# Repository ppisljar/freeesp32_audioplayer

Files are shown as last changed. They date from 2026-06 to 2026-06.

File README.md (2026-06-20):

# freeesp32_audioplayer

Open-source ESP32 audio playback board designed primarily as the hardware
platform for [**`freeesp32_ave`**](https://github.com/ppisljar/freeesp32_ave) —
audio-visual entrainment (AVE) firmware.

This repository contains the full **KiCad** project: schematic, PCB layout,
design rules, 3D models, datasheets, and helper scripts.

## Board renders

| Top | Bottom |
|---|---|
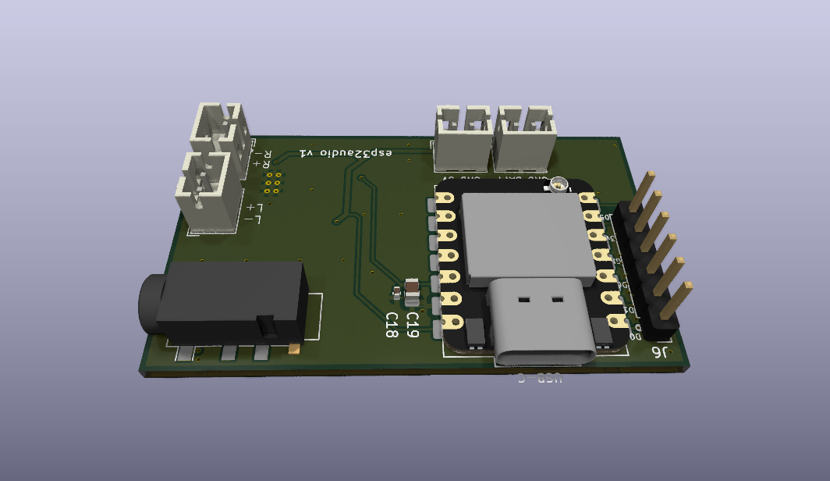
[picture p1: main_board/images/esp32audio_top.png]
Top view
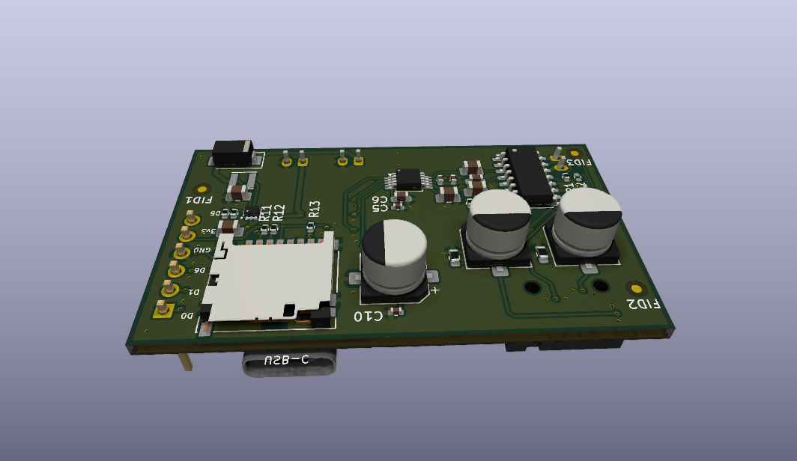
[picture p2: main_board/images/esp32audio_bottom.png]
Bottom view
|  |  |

*KiCad 3D renders. Top: TRRS headphone jack, USB-C, microSD slot, XIAO ESP32-S3 module, LED/expansion pin headers. Bottom: speaker amplifier (APA2068), bulk capacitors, level-shifting resistors.*

## Board features

- **MCU module**: Seeed Studio **XIAO ESP32-S3** (Wi-Fi + BLE)
- **Headphone output**: Cirrus Logic **CS4344** stereo I²S DAC
- **Speaker output**: **APA2068** Class-D power amplifier
- **Storage**: microSD card slot for offline audio and timeline files
- **LED outputs**: configurable headers — works with NeoPixel (WS2812),
  DotStar (APA102), or direct PWM strips (the firmware picks the backend)

## Power

The board can be powered any of three ways. The 5 V rail feeds the speaker
amplifier (APA2068), and the XIAO's onboard LDO derives the 3.3 V rail
that feeds the DAC (CS4344) and the MCU itself.

| Source | Connector | Voltage | Notes |
|---|---|---|---|
| **USB-C** | XIAO ESP32-S3 onboard | 5 V (USB VBUS) | Also used for flashing firmware and the serial console. The default during development. |
| **External 5 V** | `J4` — JST PH 2-pin (`V+_EXT`) | 5 V regulated | For powering from a bench supply, wall adapter, or upstream USB-PD trigger. |
| **Li-ion battery** | `J5` — JST PH 2-pin (`BATTERY`) | 3.0 – 4.2 V | Connects to the XIAO's `BAT+` pin. The XIAO's built-in charger manages the cell when USB is also plugged in. |

### Battery-powered audio

A single Li-ion cell sits below the 5 V needed by the speaker amplifier,
so the board includes a **TPS61023 synchronous boost converter** (`U4`)
that lifts `BAT+` up to 5 V. Output is fed into the 5 V rail through a
Schottky diode (`D1`) so the boost output can't backfeed USB VBUS when
both USB and battery are connected.

This means the speaker output works on battery just as well as on USB —
no compromise.

### Combining sources — what's safe

| Combination | Safe? | Why |
|---|---|---|
| USB + battery | ✅ Yes | XIAO charges the cell; `D1` blocks the boost from feeding USB. |
| USB + external 5 V (`J4`) | ❌ **No — pick one** | Both feed the 5 V rail directly. Hot-swapping risks back-feeding the upstream supply. |
| External 5 V + battery | ✅ Yes | Same reasoning as USB + battery — `D1` isolates the boost. |

> **Tip**: if you intend to deploy the board untethered in a meditation
> session, leave USB unplugged once you've flashed the firmware. The
> XIAO's USB controller draws current even when the host is idle.

## Repository layout

```
main_board/
├── esp32audio.kicad_sch    # schematic
├── esp32audio.kicad_pcb    # PCB layout
├── esp32audio.kicad_pro    # KiCad project
├── 3dmodels/               # STEP models for enclosure design
├── datasheets/             # IC datasheets and reference schematics
├── analysis/               # generated reports (regenerable from source)
├── images/                 # 3D renders used in this README
├── outputs/                # gerbers, drill files, BOM, pick-and-place CSVs
└── *.py                    # helper scripts (netlist sync, freerouting…)
```

## Related projects

| Repo | Role |
|---|---|
| [`freeesp32_audioplayer`](https://github.com/ppisljar/freeesp32_audioplayer) | **This repo** — open hardware (KiCad) |
| [`freeesp32_ave`](https://github.com/ppisljar/freeesp32_ave) | AVE firmware that runs on this board |
| [`freeesp32_ave_generator`](https://github.com/ppisljar/freeesp32_ave_generator) | Web editor that generates session timelines for the firmware |

## Ordering the board

The `main_board/outputs/` directory contains everything a PCB fab needs:

| File / folder | Purpose |
|---|---|
| `outputs/Archive.zip` | Gerbers + drill file (KiCad standard layer naming) |
| `outputs/esp32audio.csv` | BOM with manufacturer part numbers (MPNs) |
| `outputs/esp32audio-*-pos.csv` | Pick-and-place coordinates (top / bottom / all) |

### PCBWay (recommended for assembly with non-LCSC parts)

1. Go to <https://www.pcbway.com/orderonline.aspx> and upload `outputs/Archive.zip`. The site auto-detects board size, layer count (2-layer), and finish.
2. Defaults are fine: **FR-4, 1.6 mm, HASL or ENIG, green soldermask, white silkscreen**.
3. For assembly: enable **PCB Assembly**, upload `esp32audio.csv` (BOM) and `esp32audio-top-pos.csv` + `esp32audio-bottom-pos.csv` (CPL). PCBWay sources parts by MPN globally — useful if any component is out of stock on LCSC.
4. Quoting + DFM review typically completes within 24 h; bare-board lead time ~3–5 days, assembled ~7–10 days.

### JLCPCB (cheaper for bare boards / parts available on LCSC)

1. Go to <https://cart.jlcpcb.com/quote> and upload `outputs/Archive.zip`.
2. Defaults are fine. JLCPCB's free options match what this design needs.
3. For assembly: enable **PCBA**, upload `esp32audio.csv` (BOM) and `esp32audio-all-pos.csv` (CPL). JLCPCB requires the parts to be in their LCSC catalog — verify MPN availability before ordering, and substitute equivalents in the BOM where needed.

### Bare-board only (any fab)

Just upload `outputs/Archive.zip` — the gerbers use KiCad's standard layer naming (`F_Cu`, `B_Cu`, `F_Mask`, `B_Mask`, `F_Paste`, `B_Paste`, `F_Silkscreen`, `B_Silkscreen`, `Edge_Cuts`) which every modern fab recognises.

### Regenerating outputs from source

If you edit the schematic or PCB, regenerate the manufacturing files from KiCad:

- **PCB → File → Fabrication Outputs → Gerbers…** (use `outputs/` as the output directory, then zip)
- **PCB → File → Fabrication Outputs → Drill Files…**
- **PCB → File → Fabrication Outputs → Component Placement…** (top + bottom CPL)
- **Schematic → Tools → Generate BOM…**

## Status

Hardware design in active development. See `main_board/project_plan.md` and
`main_board/lessons_learned.md` for design notes.

## License

TBD — open hardware license to be chosen (e.g. CERN-OHL-S 2.0).

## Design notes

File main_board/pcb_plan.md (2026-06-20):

# esp32audio — PCB layout plan

Mixed-signal board with a switching boost converter and a Class-D amp.
The biggest layout risks are switching-noise coupling into the analog
audio path and inadequate return current management. Plan below is
optimised for that.

---

## 1. Board outline and stackup

| Topic | Decision |
|---|---|
| Outline target | **~42 x 32 mm** (≈ 1350 mm²), rounded 1 mm corners. Stretch goal 40 x 30. Hard ceiling 45 x 35. |
| Layer count | **2-layer**, **components on BOTH sides** to hit the size target |
| Copper weight | 1 oz (35 µm) standard |
| Substrate | FR-4, 1.6 mm |
| Top side (component-heavy) | XIAO, all 4 ICs, all connectors, the three electrolytic caps (C11, C13, C14), L1, D1 |
| Bottom side (small SMD only) | All 0603 decoupling caps, all 0603/0805 ceramics that fit, all 0603 resistors, FB divider, VOLUME divider, SE/BTL divider, FB-loop resistors |
| Stackup notes | Still 2-layer, but bottom is no longer a pure ground pour — it carries small SMDs in patches between the ground pour. Discipline: every bottom-side passive sits on a copper island connected to its corresponding top-side pin by a single via per pad. The pour fills around them. |
| Fab assumption | JLCPCB design rules (6/6 mil trace/space, 8 mil min annular, 0.3 mm min hole) |
| Assembly assumption | JLCPCB SMT both sides (extra cost vs. one side, but worth it for the area savings). Hand-solder fallback OK — all bottom parts are passives. |

Size-vs-quality reasoning: a 2-layer board with components on both
sides preserves the single-ground-pour discipline (§4) as long as
bottom-side passive islands are small and the pour stitches around
them. The audio path stays on the top layer end-to-end. The boost
island stays on the top layer end-to-end. We only lose pour
continuity in patches under decoupling caps — those patches are
< 5 mm wide and shielded by the IC body above, so they do not
disrupt audio return paths.

Switching node area, audio bandwidth, and ground-pour discipline
arguments still apply unchanged from the single-side plan.

---

## 2. Floor plan — XIAO on south edge, USB-C facing south

```
       ┌──────────────────────────────────────────────────┐
       │ [J5 BAT screw]    [J4 V+ JST]      [J1 3.5mm jack]│  NORTH edge
       │                                                  │
       │ [boost island:                     [J2 L spkr]    │  (connectors NORTH)
       │   U4,L1,C16,                                      │
       │   C17,D1]          [APA2068 U3]    [J3 R spkr]    │
       │                                                  │
       │ [J6 GPIO     [CS4344 U2]                          │
       │   breakout                                        │
       │   1x10       (audio chain in middle row)          │
       │   pin hdr]                                        │
       │                                                  │
       │      [────  XIAO ESP32-S3 (U1) ────]              │  SOUTH edge
       └────────────────↓ USB-C overhang ↓────────────────┘
                       (clear board edge south)
```

The XIAO is the size-driver. Pinning its USB-C to one edge defines
that edge; everything else fits around it.

**XIAO orientation (locked):**

- XIAO long axis runs **east-west** along the south edge of the
  board.
- USB-C connector points **south**, overhanging the board edge by
  ~1.5 mm so the USB-C plug shell clears any silkscreen / soldermask
  pile-up.
- Castellated mount: BAT+ SMD pad (bottom of XIAO module) sits on a
  matching copper land on the top layer of the board. Verify the
  XIAO_ESP32-S3_SMD footprint exposes this pad; if it does not, fix
  the .kicad_mod before placement.
- Board edge directly under the USB-C must be straight (no rounded
  corner) for ~6 mm centered on the connector — round corners
  reduce strain relief but a USB-C plug needs a flat seat.
- No tall components within 3 mm north of the XIAO body — the
  module's antenna sits on its top face and benefits from clear
  space.

Edge ownership (so cables don't fight):

| Edge | Connectors |
|---|---|
| North | J5 battery screw (left), J4 V+ JST (center), J1 headphone (right) |
| East | J2 L speaker, J3 R speaker (stacked vertically) |
| West | J6 GPIO breakout (1x10 SIL header, vertical) |
| South | XIAO U1, USB-C overhang only — no other connector |

Trade-off: J5 (battery screw) and J1 (headphone) on the same edge
means the user must route the battery wire away from the headphone
plug when the device is held normally. Acceptable — the alternative
(headphone on east, speakers on north) makes the east edge cluttered
with one BIG part and three small ones.

---

## 2a. Top vs bottom side assignment

Every part is placed on exactly one of the two sides. The board is
designed so that **everything on the bottom is a small passive** —
no ICs, no electrolytics, no connectors, no tall parts on the
bottom. This keeps assembly cheap and lets the board sit flat on a
case.

### TOP side (north view)

All ICs, the XIAO module, all connectors, all electrolytic /
through-hole / tall parts, the boost inductor and Schottky.

| Ref | Part | Reason for top |
|---|---|---|
| U1 | XIAO ESP32-S3 module | Castellated SMD; antenna up |
| U2 | CS4344 TSSOP-10 | Main IC |
| U3 | APA2068 SOP-16-EP | Main IC, EP needs top-side via field |
| U4 | TPS61023 SOT-563 | Main IC |
| L1 | 4.7 µH SMD inductor | Tall, magnetic — keep above plane |
| D1 | SS14 Schottky | Part of boost loop, keep with L1 |
| C11 | 100 µF electrolytic | Tall radial / SMD lead |
| C13 | 220 µF electrolytic (HP L) | Tall |
| C14 | 220 µF electrolytic (HP R) | Tall |
| J1–J6 | All connectors | Through-hole or large SMD |

### BOTTOM side (small SMD passives only, 0603/0805)

| Ref | Part | Goes near |
|---|---|---|
| C2 | 0.1 µF | Under CS4344, snug to pin 9 (VA) |
| C3 | 1 µF | Under CS4344, near pin 9 |
| C4 | 10 µF | Under CS4344, snug to pin 6 (FILT+) |
| C5 | 0.1 µF | Under CS4344, snug to pin 5 (VQ) |
| C6 | 3.3 µF | Under CS4344, near pin 5 |
| C7 | 3.3 µF poly | Mid-path CS4344↔APA2068 (could be on top if 0805 polarised cap is fine on top) |
| C8 | 3.3 µF poly | Mid-path CS4344↔APA2068 |
| C9 | 0.1 µF | Under APA2068, snug to pin 10 (VDD) |
| C10 | 0.1 µF | Under APA2068, snug to pin 15 (VDD) |
| C12 | 2.2 µF | Under APA2068, snug to pin 4 (BYPASS) |
| C15 | 0.1 µF | Under APA2068, snug to pin 7 (VOLUME) |
| C16 | 10 µF | Under U4, snug to pin 3 (VIN). Keep on TOP if it fits the boost-island rule (see §3.1) |
| C17 | 22 µF | Under U4, snug to pin 6 (VOUT). Same caveat |
| R1, R2 | 100k | Under APA2068, near pin 13 (SE/BTL) |
| R3, R4 | 1k | Under HP path, near J1 |
| R7, R8 | VOLUME divider | Under APA2068, near pin 7 |
| R9, R10 | FB divider | Under U4, near pin 1 (FB) |

**Caveat for C16, C17:** the boost-island rule (§3.1) requires the
input/output caps to close their current loop with U4 via the
shortest possible path. If putting C16/C17 on the bottom forces the
loop to detour through vias (adding inductance), keep them on the
top side flanking U4 instead. Decide during placement based on what
visually closes the loop tightest. The rest of the bottom-side
assignments are unconditional.

### Bottom-side ground-pour rule

The bottom layer is **mostly ground pour**, with small copper
patches for the bottom-side passive pads. Each bottom-side pad
connects to its top-side function via a single via per pad, placed
on the pad itself (via-in-pad, or tab-and-via if fab forbids
via-in-pad). The pour stitches around these patches.

Result: viewed from below, the board looks like solid copper with a
few tiny copper-and-pad islands. The audio return path under
top-side traces is preserved everywhere except those islands.

---

## 2b. Size optimization checklist

Run through this list during placement. Each item is worth 1–5 mm²
of saved area.

- [ ] **XIAO USB-C overhangs the south edge** (saves ~3 mm of board
      length compared to fully containing the connector)
- [ ] **All small passives on the bottom side** (saves the area they
      would otherwise occupy on top)
- [ ] **Decoupling caps directly under their IC pin** (zero
      additional top-side area)
- [ ] **No silkscreen reference designators on tight bottom-side
      patches** — they push pours apart; use a separate top-side ref
      legend or rely on the BOM for ref positions
- [ ] **JST PH-2 connectors share centerlines** where multiple sit
      on the same edge (J4 with J2/J3 styled the same, mounted
      flush)
- [ ] **J6 GPIO header oriented vertically along west edge** (uses
      the full west edge in one strip instead of a horizontal block
      that eats interior area)
- [ ] **APA2068 EP vias fit inside the package footprint** (no extra
      copper required beyond the EP outline)
- [ ] **Boost island fits in a 12 x 12 mm square**; if it spreads
      beyond that, re-pack
- [ ] **No "test point" pads on v1** — leave testpoints for v1.1 if
      we discover we need them. Each TP eats 2.5 mm²
- [ ] **Mounting holes deferred to v1.1** OR use M2 holes (≤ 4.5 mm
      keep-out each), placed only at two diagonal corners
- [ ] **Silkscreen kept to essentials**: pin 1 dots, polarities,
      J5/J6 labels, board name. No full pinouts on every connector.

### Realistic size budget

| Element | Area used |
|---|---|
| XIAO under-area (21 x 17.5) | 367 mm² |
| APA2068 + decoupling | ~50 mm² |
| CS4344 + decoupling | ~30 mm² |
| Boost island | ~120 mm² |
| C11, C13, C14 electrolytics | ~90 mm² |
| Connectors (J1–J6) | ~440 mm² |
| J6 header strip | ~75 mm² |
| Routing / clearance | ~200 mm² |
| **Total** | **~1372 mm²** ≈ 41 x 33 mm |

Target **42 x 32 mm** is achievable. Stretch goal **40 x 30 mm**
requires shrinking the headphone jack footprint or putting C13/C14
on the bottom (which conflicts with the electrolytic-on-top rule
unless we use ceramic instead).

### Size-saving substitutions (BOM changes, optional)

These are not in v1 BOM but listed so we can pull them in if we
overshoot the target:

| Original | Alternative | Area saved | Trade-off |
|---|---|---|---|
| C11 100 µF radial electrolytic (6.3 mm) | 22 µF ceramic 1210 X5R 10V | ~25 mm² | Lower bulk capacitance; APA2068 may dip on transients |
| C13, C14 220 µF radial electrolytic (6.3 mm) each | 100 µF ceramic 1210 X5R 10V | ~50 mm² total | High-pass corner shifts up; check ≥ 20 Hz still met with 1 kΩ R3/R4 |
| PJ-320A through-hole jack (13×14 mm) | SMD 3.5 mm jack (e.g. CUI SJ-43514) | ~80 mm² | More expensive part, harder to source |
| J5 5.08 mm screw terminal | 2.5 mm screw terminal or JST XH-2 | ~40 mm² | Smaller wire gauge |

---

## 3. Power partitioning — the single most important thing

Split the board mentally into three power domains:

1. **Battery / boost** (BAT+, BOOST_SW, BOOST_OUT, FB) — high di/dt, switching
2. **Clean +5V** (downstream of D1 / XIAO 5V pin) — feeds APA2068 VDD
3. **Clean +3V3** — feeds CS4344 VA only

These overlap on the same ground plane, but their **current loops
must not cross each other**. Plan:

### 3.1 Boost loop (highest priority)

The TPS61023 boost loop carries the largest di/dt on the board. Keep
this loop physically tiny:

```
        BAT+ ──► C16 ──► U4 pin 3 (VIN)
                          U4 pin 5 (SW) ──► L1 ──► U4 pin 6 (VOUT)
                                                    │
                                                    ├──► C17 ──► GND
                                                    └──► D1 anode → D1 cathode → +5V rail
        GND ◄────────────── U4 pin 4 (GND), C16, C17, D1 cathode return
```

**Rules:**
- C16, U4, L1, C17, D1 cluster into a < 10 x 10 mm island in the
  north-center of the board.
- L1 sits directly between U4 SW pin and U4 VOUT pin — keep the SW
  copper area small (it is the noisiest node on the board).
- C16 (input cap) ground pin and U4 GND pin **share a ground via**
  (or copper short) — do not let the input current loop close
  through the broader ground plane.
- C17 (output cap) ground pin and U4 GND pin same rule.
- D1 cathode → +5V rail leaves the boost island via a **single
  trace**, ≥ 0.6 mm wide, that crosses into the amp area.
- FB divider (R9, R10) is on a **quiet copper** — keep R9/R10 away
  from the SW node. The FB trace from U4 pin 1 to the R9/R10
  junction is < 5 mm. Run it on the side of U4 opposite to L1.
- No ground plane cut under the boost loop — solid pour underneath
  the entire island.

### 3.2 +5V rail to amp

C9, C10 (0.1 µF HF decoupling) sit **within 1 mm of APA2068 pin 10
and pin 15** respectively, with the shortest possible ground via.

C11 (100 µF bulk) within 5 mm of APA2068.

Trace from boost island to APA2068 VDD: ≥ 0.6 mm wide, kept on top
layer, routed around the audio signal area (do not run +5V across
the CS4344 analog outputs).

### 3.3 +3V3 rail

XIAO 3V3 pin → CS4344 VA pin (pin 9). Single trace, ≥ 0.3 mm,
< 25 mm long. C2 (0.1 µF) within 1 mm of CS4344 pin 9. C3 (1 µF)
within 5 mm. Do **not** share this trace with any other +3V3 sink
except J6 pin 9 (breakout).

---

## 4. Ground strategy

**Single solid ground pour on the bottom layer.** No analog/digital
split. The board is too small to gain anything from a split, and a
split done wrong is worse than no split at all.

Discipline instead of split:

- **APA2068 EP (thermal pad)** is the highest-current return on the
  board. Sew it to the ground plane with **at least 6 vias** (0.3 mm
  drill, 0.6 mm pad). The EP is also the thermal exit path — these
  vias matter for both thermal and electrical reasons.
- **CS4344 GND (pin 8)** has its own dedicated via to the bottom
  plane, placed within 1 mm of the pin.
- **C5, C6 (VQ caps), C4 (FILT+ cap), C2, C3 (VA caps)** — each
  ground pin gets its own via to the bottom plane, no daisy chains.
- **Boost island** ground vias as listed in §3.1.
- **Headphone jack sleeve (J1.S)** ground via at the connector body.
- **Speaker connector grounds**: J2 pin 1 and J3 pin 1 are NOT GND
  on this design (they are SPK_L_NEG and SPK_R_NEG — BTL output
  legs). Do not accidentally pour ground onto them.
- **J6 pin 8 (GND breakout)** — direct via to plane at the connector.

Return path check: trace the return current for the I²S signals from
CS4344 back to XIAO GND. It should follow the I²S trace on the
bottom plane uninterrupted. If you add any cuts to the bottom pour,
sanity-check return paths first.

---

## 5. Signal routing

### 5.1 I²S bus (XIAO D7–D10 → CS4344 pins 1–4)

Four signals: BCLK, LRCK, SDIN, MCLK. MCLK is the fastest
(typically 12.288 MHz for 48 kHz audio).

- Length match within ~5 mm (not critical at these speeds, but easy
  to do and good hygiene).
- Trace width 0.2 mm.
- **Do not route the I²S bus over the SW node or over L1.**
- Keep at least 1 mm separation from the boost island.
- Route on top layer, ground return on the bottom layer directly
  beneath.

### 5.2 Analog audio path — CS4344 AOUTL/R → APA2068 LIN-/RIN-

This is the most noise-sensitive path on the board. AOUTL/R are
single-ended ~1 Vpp signals.

- Total path length **< 25 mm** per channel.
- DC-block caps C7, C8 sit **between** CS4344 and APA2068 (mid-path).
- Trace width 0.25 mm.
- Route on top layer with solid ground beneath on bottom layer.
- **Keep at least 2 mm from any switching trace (SW node, I²S MCLK,
  USB DP/DM if exposed).**
- No vias on these traces — keep them on a single layer.

### 5.3 Speaker outputs (BTL, differential)

Pairs: (LOUT+, LOUT-) → J2, (ROUT+, ROUT-) → J3.

- Route as **tightly-coupled pairs** (0.25 mm trace, 0.25 mm gap)
  from APA2068 to the connector. This minimises radiated emissions
  from the PWM modulation.
- Trace width 0.4 mm minimum (current capacity for ~1 W into 4–8 Ω).
- Length: keep under 30 mm. Speaker leads outside the board do the
  EMI work, so the on-board portion should be short and parallel.
- If radiated emissions become a problem in testing, the standard
  fix is a ferrite bead + small cap LC filter at each output. Leave
  placeholder room near J2 and J3 for two 0603 footprints per
  channel (BOM-optional).

### 5.4 Headphone outputs

C13, C14 (220 µF AC-coupling) sit close to J1, **not** close to
APA2068 — the long trace is on the BTL side (which is differential
and tolerant), the short trace is on the single-ended HP side.

- C13: APA2068 LOUT- → C13 (+) → C13 (-) → J1.T (tip)
- C14: APA2068 ROUT- → C14 (+) → C14 (-) → J1.R (ring)
- R3, R4 (1 kΩ load reference) placed near J1.

### 5.5 SE/BTL detect

R1 (100k pull-up), R2 (100k series), J1.SN (sleeve switch).

- Place R1 near APA2068 pin 13.
- Place R2 mid-way between R1 and J1.
- Run R2-to-J1.SN as a quiet trace (no special width, no shielding,
  but keep it on the top layer).

### 5.6 VOLUME divider

R7 (100k), R8 (10k), C15 (0.1 µF) → APA2068 pin 7. Place all three
within 5 mm of APA2068 pin 7. The 0.45 V bias node is high-impedance
(~9 kΩ), so it is sensitive to capacitive coupling from PWM — keep
C15 close to the pin to shunt any pickup.

---

## 6. Trace width reference

| Net | Width | Reason |
|---|---|---|
| +5V (boost output → APA2068 VDD) | 0.6 mm | Peak current ~1 A |
| +5V (APA2068 → J6 pin 10 breakout) | 0.4 mm | Lower current |
| +3V3 | 0.3 mm | < 100 mA |
| BAT+ (J5 → C16 → U4) | 0.6 mm | Boost input current |
| BOOST_SW (U4 pin 5 → L1) | 0.5 mm copper region | Switching node, keep area small not skinny |
| BOOST_OUT (L1 → D1 → C17) | 0.6 mm | High di/dt |
| GND vias | 0.3 mm drill / 0.6 mm pad | Standard, low-impedance |
| Speaker outputs | 0.4 mm | Audio current |
| I²S, MCLK | 0.2 mm | Signal only |
| Audio AOUT L/R | 0.25 mm | Signal, low impedance |
| Headphone outputs (C13/C14 to jack) | 0.3 mm | < 100 mA |
| FB_NET | 0.2 mm | Sense, low impedance |
| SE_BTL, J1_SW | 0.2 mm | Logic |
| Everything else | 0.2 mm default | |

Track-to-track clearance: 0.2 mm (8 mil) minimum. Default 0.25 mm.

---

## 7. Component placement order

Place in this order so each step constrains the next:

1. **Set DRC and board outline** to the size target (42 x 32 mm
   working, 45 x 35 mm hard ceiling). Mounting holes deferred to
   v1.1.
2. **XIAO ESP32-S3 first**, locked to the south edge with USB-C
   overhanging south. This is the largest single part and dictates
   everything else.
3. **Edge connectors next** (J1, J2, J3, J4, J5, J6), placed on
   their assigned edges per §2.
4. **APA2068** — locked in the east-center area, with output pins
   (LOUT, ROUT, pins 9–16) facing east toward J2/J3.
5. **CS4344** — locked west of APA2068, I²S pins (1–4) facing west
   toward XIAO, AOUT pins (7, 10) facing east toward APA2068.
6. **TPS61023 + L1 + C16 + C17 + D1** — boost island in the
   north-west corner, between J5 and the audio chain.
7. **Flip board, place bottom-side decoupling caps directly under
   their IC pins** (C2, C3, C4, C5, C6 under CS4344; C9, C10, C12,
   C15 under APA2068). Goal: zero added top-side area for
   decoupling.
8. **Bottom-side dividers and small resistors** (R1, R2, R7, R8,
   R9, R10, R3, R4) placed near the pins they feed.
9. **Top-side audio coupling caps** (C7, C8) in their signal paths
   between CS4344 and APA2068. **Top-side electrolytics** (C11,
   C13, C14) near their ICs / connectors.
10. **Decide C16, C17 placement** (top vs bottom) by which option
    closes the boost loop tightest. Default top if in doubt.
11. **Routing pass**: power first, then audio (top side only), then
    I²S, then everything else.
12. **Pour ground**: bottom layer first as the primary plane, top
    layer as a secondary pour filling open areas. Stitch with
    ground vias every ~5 mm in quiet regions; denser around the
    boost island and APA2068 EP.

Do not move an IC after its decoupling caps are placed — re-do the
caps from scratch instead.

When a bottom-side cap conflicts with a routing channel needed on
the bottom, prefer to route on the top and keep the cap on the
bottom. Top-side routing tolerates jogs better than bottom-side
ground-pour does.

---

## 8. Polarity, orientation, silkscreen

Mark on silkscreen:

- **J5 battery**: clearly label `BAT+` and `BAT-` (this is a screw
  terminal a user wires by hand — getting it wrong destroys the
  board)
- **J4 V+ JST**: label `+5V` and `GND` with pin 1 indicator
- **J2, J3 speakers**: pin 1 = NEG, pin 2 = POS (mark + on pin 2 so
  speaker phase is obvious)
- **J6 breakout**: full pinout label `D0 D1 D2 D3 D4 D5 D6 GND 3V3 5V`
- **Electrolytic caps (C7, C8, C11, C13, C14)**: + side clearly marked
- **D1**: cathode bar visible
- **U1 XIAO**: pin 1 indicator + orientation arrow
- **U2 CS4344, U3 APA2068, U4 TPS61023**: pin 1 dots
- Board name, version, date in the corner: `esp32audio v1` /
  `2026-06` / `CS4344`

---

## 9. Thermal

APA2068 worst-case dissipation:
- 2 channels × 1 W output × (1 - efficiency). Class-D at 5 V into
  4 Ω is roughly 85% efficient → ~0.35 W total dissipation max.
- EP thermal pad with 6× 0.3 mm vias to a ≥ 100 mm² bottom-side
  copper pour handles this with margin.

TPS61023 worst-case dissipation:
- 1 A boost from 3.7 V to 5 V, ~92% efficiency → ~0.4 W internal.
- SOT-563 thermal pad on the package; rely on PCB copper around
  pins for heat spreading. Pour a ~50 mm² copper region around U4.

No active cooling needed.

---

## 10. EMC / EMI checklist before fab

- [ ] SW node copper area < 50 mm² (visually inspect the boost
      island)
- [ ] No analog audio traces cross the SW node or pass within 2 mm
      of L1
- [ ] Speaker output pairs routed as tight differential pairs
- [ ] Ground pour continuous under all signal traces — no slots,
      no large cuts
- [ ] C16/C17 ground vias share copper with U4 GND pin
- [ ] APA2068 EP has ≥ 6 ground vias
- [ ] +5V trace from boost to APA2068 does not weave through the
      audio area
- [ ] Boost feedback divider trace is on the side of U4 opposite
      to L1
- [ ] All decoupling caps within 1 mm of their IC power pin

---

## 11. DRC settings

Set in KiCad before routing:

| Constraint | Value |
|---|---|
| Minimum clearance | 0.2 mm |
| Minimum trace width | 0.15 mm |
| Default trace width | 0.25 mm |
| Minimum via diameter | 0.6 mm (pad) / 0.3 mm (drill) |
| Minimum annular ring | 0.1 mm |
| Minimum hole-to-hole | 0.5 mm |
| Edge clearance | 0.3 mm |

Net classes:

| Class | Width | Members |
|---|---|---|
| Power | 0.6 mm | +5V, BAT+, BOOST_OUT |
| Audio | 0.25 mm | AOUTL/R_RAW, AOUTL/R_AC, HP_L, HP_R |
| Speaker | 0.4 mm | SPK_L_NEG/POS, SPK_R_NEG/POS |
| I2S | 0.2 mm | I2S_BCLK, I2S_LRCK, I2S_DOUT, I2S_MCLK |
| Default | 0.25 mm | Everything else |

---

## 12. Pre-fab gates

Before sending gerbers:

1. **DRC clean** — zero errors, zero warnings (or each warning
   reviewed and justified)
2. **Visual ground-pour inspection** — pour continuous on bottom,
   no orphaned islands, all ground pins connected via thermal relief
   or solid copper
3. **Return path trace** — pick three signals (an I²S line, the
   audio AOUTL, the LOUT speaker), mentally trace return current,
   confirm uninterrupted ground beneath
4. **3D render check** — connectors at edges, USB-C clear, no
   collisions, polarised parts oriented correctly
5. **Footprint review** — every footprint matches the actual part
   (especially the custom ones: XIAO, APA2068 SOP-16-EP, TPS61023
   SOT-563). Cross-check pad sizes against datasheet recommended
   land patterns.
6. **BOM cross-check** — every reference in the schematic appears
   on the PCB and has a value, footprint, and (ideally) JLCPCB part
   number assigned.

---

## 13. Known risks / things to watch

| Risk | Mitigation |
|---|---|
| XIAO BAT+ pad orientation in footprint may be wrong | Verify against XIAO datasheet before placement; if wrong, fix the .kicad_mod |
| APA2068 cached symbol mismatch warning in ERC | Open in KiCad UI, Tools → Update Symbols from Library, re-save |
| TPS61023 symbol pin types are bidirectional, not power_in/out | Cosmetic ERC warnings; functional. Optionally tighten pin types in New_Library |
| Audio coupling via L1 fringing field into AOUTL/R traces | L1 is shielded inductor; place ≥ 5 mm from CS4344 outputs |
| Speaker cable radiation under FCC class B | Add LC output filter footprints (DNP by default), populate if needed |
| Hand-routing speaker BTL pairs may not stay tightly coupled | Use route_differential_pair tool in KiCad MCP for J2/J3 pairs |
| Ground pour leaving voids near dense BGA-like via clusters | Inspect after pour fill; manually patch with copper if needed |
| Bottom-side decoupling cap pad islands break the ground pour and degrade return paths | Keep each bottom-side pad cluster < 5 mm wide. Verify pour fills around them (no isolated copper pieces). For any spot where pour fragmentation looks bad, move that cap back to the top. |
| Bottom-side ground pour fragmented under the audio path | After routing, manually scan the bottom layer under each top-side audio trace (AOUTL/R_AC, HP_L/R). Continuous copper required. |
| XIAO USB-C plug shell hitting nearby components | 3D-render and verify ≥ 1.5 mm clearance around the USB-C body on the south edge before fab |
| Double-sided assembly cost increase (JLCPCB) | Confirmed acceptable for v1 prototype quantity. If scaling, revisit single-side layout. |
| Headphone jack J1 too close to battery screw J5 on the north edge | Maintain ≥ 10 mm horizontal gap between the two; user routes wires opposite directions |
| Audio coupling caps C7/C8 forced to the bottom (polarised SMD electrolytics) | If using polarised SMD parts, the bottom-side placement is fine. If we substitute non-polar film caps that are too tall for the bottom, move to top and accept ~5 mm² area cost. |

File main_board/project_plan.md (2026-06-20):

# esp32audio — CS4344 version, build plan

**Goal:** Small audio board. XIAO ESP32-S3 streams I²S → CS4344 stereo DAC → APA2068 stereo class-D amp.

**Outputs:**
- 2× speaker connectors (stereo, JST PH-2, BTL drive)
- 1× 3.5 mm stereo headphone jack with auto-detect (APA2068 SE/BTL mode toggle)

**Inputs:**
- USB-C on the XIAO (development)
- External `V+/GND` JST PH-2 (5 V wall adapter)
- Li-ion battery on screw terminal → XIAO BAT+ → TPS61023 boost → 5 V rail

**v1 scope:** CS4344 only. PCM5101A deferred to a separate v2 project.

**v1.1 additions** (this revision):
- **microSD card** on SPI (CS, MOSI, MISO, SCK). 4 pins from XIAO D1–D4. No CD switch (firmware polls).
- **0402 passives** for all standard R/C (replacing 0603/0805 where possible). Saves ~40 mm² board area.
- J6 breakout reduced from D0–D6 to D0, D5, D6 (D1–D4 reassigned to SD card).

---

## Final design decisions (all locked in)

| Topic | Decision | Notes |
|---|---|---|
| DAC | CS4344 only (v1) | PCM5101A deferred |
| Amp | APA2068 in BTL stereo, SE switch via headphone jack | |
| MCU module | Seeed XIAO ESP32-S3, **SMD castellated mount** | BAT+ pad needs SMD electrical contact |
| Speakers | Stereo, 2× JST PH-2 (J2 = L, J3 = R) | |
| Headphone | 3.5 mm TRS w/ switched detect (J1) | e.g. PJ-320A |
| External 5 V in | JST PH-2 (J4), parallel with USB VBUS | "USB ⊕ V+, one at a time" |
| Battery | 2-pos screw terminal (J5) → XIAO BAT+ | XIAO's onboard charger handles management |
| Battery → 5 V | TPS61023 boost (U4), BAT+ → Vout via D1 Schottky to 5 V rail | enables headphone audio on battery |
| GPIO breakout | J6 = **1×10 SIL** pin header (D0–D6, GND, +3V3, +5V) | |
| Diode-OR USB/V+ | No (mutually exclusive) | USB + battery is the only "both-at-once" case, handled by D1 |
| MUTE / SHUTDOWN | Tied directly to +5V (always enabled) | Mute = stop I²S in firmware |
| VOLUME | Fixed +14 dB via R7=100k / R8=10k divider on VOLUME pin | Volume controlled in software (DAC level) |
| SE/BTL | 100 k pull-up + 100 k series to jack-switch contact → GND | Verified vs datasheet VIH=4V, VIL=3V |
| CS4344 VA | 3.3 V from XIAO 3V3 pin | XIAO LDO is clean enough for ~100 dB SNR |

---

## Block diagram

```
                                         ┌──────────────────────────────────────┐
   USB-C  ──► XIAO 5V pin ──┬─────────────┤                                      │
                            │             │     +5V rail                         │
                            │             │   ┌──────────────► APA2068 VDD (10,15)
                            │             │   │
   J4 V+ JST ───────────────┘             │   ├─── decoupling C9, C10, C11
                                          │   ├─── R1 → SE/BTL
                                          │   ├─── R7 → VOLUME divider
                                          │   ├─── APA2068 ~MUTE, ~SHUTDOWN tied here
                                          │   │
   J5 BAT screw ── BAT+ ──► XIAO BAT+ ──► U4 TPS61023 ──L1──► VOUT ──► D1 Schottky
                                          (boost VIN)            (SS14)

                                          XIAO 3V3 pin ──► +3V3 rail ──► CS4344 VA (9)
                                                                          + C2, C3 decoupling

                                          XIAO D7  ──► CS4344 SCLK (2)   I2S_BCLK
                                          XIAO D8  ──► CS4344 LRCK (3)   I2S_LRCK
                                          XIAO D9  ──► CS4344 SDIN (1)   I2S_DOUT
                                          XIAO D10 ──► CS4344 MCLK (4)   I2S_MCLK

                                          XIAO D0..D6 → J6 breakout (+3V3, +5V, GND also on J6)

   CS4344 AOUTL (7) ── C7 3.3µ → APA2068 LIN- (6)
   CS4344 AOUTR (10)── C8 3.3µ → APA2068 RIN- (3)
   CS4344 VQ (5)  ────── C5 0.1µ, C6 3.3µ → GND
   CS4344 FILT+ (6) ──── C4 10µ → GND

   APA2068 LOUT- (9)  ──┬─► J2 (L spkr) pin 1
                        └─ C13 220µ ─► J1 Tip (HP L) ── R3 1k → GND
   APA2068 LOUT+ (11) ──► J2 (L spkr) pin 2
   APA2068 ROUT- (16) ──┬─► J3 (R spkr) pin 1
                        └─ C14 220µ ─► J1 Ring (HP R) ── R4 1k → GND
   APA2068 ROUT+ (14) ──► J3 (R spkr) pin 2

   APA2068 SE/BTL (13) ── R1 100k ▲ +5V
                       ── R2 100k ── J1 SW → GND
   APA2068 BYPASS (4)  ── C12 2.2µ → GND
   APA2068 VOLUME (7)  ── R7 100k ▲ +5V, R8 10k ▼ GND, + C15 0.1µ → GND   (0.45 V → +14 dB)
   APA2068 VOLMAX (8)  ── GND
   APA2068 ~MUTE (1)   ── +5V
   APA2068 ~SHUTDOWN(2)── +5V
   APA2068 EP (17)     ── GND
```

---

## Power tree

| Net | Sourced by | Sinks |
|---|---|---|
| `+5V` | XIAO 5V pin (USB VBUS) **OR** J4 V+ JST **OR** TPS61023 VOUT via D1 (when on battery) | APA2068 VDD (10, 15), APA2068 ~MUTE (1), APA2068 ~SHUTDOWN (2), R1 (SE/BTL pull-up), R7 (VOLUME top), C9, C10, C11, C17 (boost output cap), J6 pin 10 |
| `+3V3` | XIAO 3V3 pin (XIAO internal LDO) | CS4344 VA (9), C2, C3, J6 pin 9 |
| `BAT+` | J5 screw terminal pin 1 ↔ XIAO BAT+ | TPS61023 VIN, C16 (boost input cap) |
| `GND` | XIAO GND pin | Every return |

Notes:
- USB-C → XIAO 5V pin directly drives the +5V rail (no Schottky drop) → APA2068 sees full 5 V on USB.
- On battery only (USB unplugged): TPS61023 boost output goes through D1 Schottky (≈0.3 V drop) → +5V rail sits at ≈4.7 V → APA2068 still in spec (min 4.5 V).
- USB plugged in + battery present: USB holds +5V rail at 5 V; boost output sees its cathode at 5 V → reverse-biases D1 → boost backs off to light-load mode (~30 µA from battery). XIAO charger tops up the battery.

---

## XIAO ESP32-S3 (U?) pin assignment

(Reference designator will be assigned during schematic capture.)

| Pin | Name | Function | Net |
|----:|---|---|-----|
|  1  | D0/GPIO1 | breakout | `D0` → J6 pin 1 |
|  2  | D1/GPIO2 | Free breakout GPIO | `D1_NET` → J6 pin 2 |
|  18 | GPIO42 (bottom pad) | SD card CS | `SD_CS` → J7 (microSD), R11 pull-up |
|  3  | D2/GPIO3 | SD card SCK | `SD_SCK` → J7 (microSD) |
|  4  | D3/GPIO4 | SD card MOSI | `SD_MOSI` → J7 (microSD) |
|  5  | D4/GPIO5 | SD card MISO | `SD_MISO` → J7 (microSD) |
|  6  | D5/GPIO6 | breakout (SCL-capable) | `D5` → J6 pin 2 |
|  7  | D6/GPIO43  | breakout (UART0 TX) | `D6` → J6 pin 3 |
|  8  | D7/GPIO44  | I²S BCLK | `I2S_BCLK` → CS4344 pin 2 |
|  9  | D8/GPIO7 | I²S LRCK | `I2S_LRCK` → CS4344 pin 3 |
| 10  | D9/GPIO8 | I²S DOUT | `I2S_DOUT` → CS4344 pin 1 |
| 11  | D10/GPIO9  | I²S MCLK | `I2S_MCLK` → CS4344 pin 4 |
| 12  | 3V3 | power out  | `+3V3` |
| 13  | GND | gnd return | `GND` |
| 14  | 5V | USB VBUS | `+5V` |
| 15  | BAT+ | Li-ion I/O | `BAT+` |

---

## CS4344 (U2) — 10-pin MSOP, VA = 3.3 V

| # | Name | Net | Component |
|--:|---|-----|---|
|  1 | SDIN | `I2S_DOUT` |  |
|  2 | DEM/SCLK | `I2S_BCLK` |  |
|  3 | LRCK | `I2S_LRCK` |  |
|  4 | MCLK | `I2S_MCLK` |  |
|  5 | VQ | `VQ_NET` | C5 0.1 µF + C6 3.3 µF → GND |
|  6 | FILT+ | `FILT_NET` | C4 10 µF → GND |
|  7 | AOUTL | `AOUTL_AC` | + side of C7 3.3 µF → APA2068 pin 6 |
|  8 | GND | `GND` |  |
|  9 | VA | `+3V3` | C2 0.1 µF + C3 1 µF → GND |
| 10 | AOUTR | `AOUTR_AC` | + side of C8 3.3 µF → APA2068 pin 3 |

DC-block cap polarity: `+` on CS4344 side.

---

## APA2068 (U3) — SOP-16-P with EP

| # | Name | Net | Component |
|--:|---|-----|---|
|  1 | ~MUTE | `+5V` | tied directly (always on) |
|  2 | ~SHUTDOWN  | `+5V` | tied directly (always on) |
|  3 | RIN- | `AOUTR_AC`  | from CS4344 via C8 |
|  4 | BYPASS | `BYPASS_C`  | C12 2.2 µF → GND |
|  5 | GND | `GND` |  |
|  6 | LIN- | `AOUTL_AC`  | from CS4344 via C7 |
|  7 | VOLUME | `VOLUME_C`  | R7 100k → +5V; R8 10k → GND; C15 0.1 µF → GND |
|  8 | VOLMAX | `GND` | clamp disabled |
|  9 | LOUT- | `SPK_L_NEG` | J2 pin 1; C13 (+) 220 µF → J1 Tip |
| 10 | VDD | `+5V` | C9 0.1 µF + C11 100 µF → GND |
| 11 | LOUT+ | `SPK_L_POS` | J2 pin 2 |
| 12 | GND | `GND` |  |
| 13 | SE/~BTL | `SE_BTL` | R1 100k → +5V; R2 100k → J1 SW |
| 14 | ROUT+ | `SPK_R_POS` | J3 pin 2 |
| 15 | VDD | `+5V` | C10 0.1 µF → GND |
| 16 | ROUT- | `SPK_R_NEG` | J3 pin 1; C14 (+) 220 µF → J1 Ring |
| 17 | EP | `GND` | thermal pad + 6 vias |

---

## TPS61023 boost block (U4)

| # | Name | Net | Component |
|--:|---|-----|---|
|  1 | FB | `FB_NET` | R9 (top) to VOUT, R10 (bottom) to GND  → sets 5 V output (see below) |
|  2 | EN | `BAT+` | tied to VIN → boost always on |
|  3 | VIN | `BAT+` | C16 10 µF → GND |
|  4 | GND | `GND` |  |
|  5 | SW | `BOOST_SW` | L1 (4.7 µH) between SW and VOUT |
|  6 | VOUT | `BOOST_OUT`  | C17 22 µF → GND; through D1 (SS14) → `+5V` rail |

**Feedback divider:** TPS61023 VFB = 0.6 V. For 5 V output: VOUT/VFB = 8.33 → R9/R10 = 7.33. Standard values: **R9 = 365 kΩ (or 360 kΩ), R10 = 49.9 kΩ**, giving 5.0 V; or R9 = 100 kΩ, R10 = 13.7 kΩ.

**Schottky D1:** SS14 (1 A, 40 V) or PMEG2010AEH. Drop ~0.3 V at 1 A. Cathode = +5V rail, anode = BOOST_OUT.

---

## Headphone jack J1

3.5 mm stereo TRS jack with switched detect contact (PJ-320A or equivalent).

| Contact | Net | Notes |
|---|---|---|
| Tip (L) | `HP_L` | + of C13 → APA2068 LOUT-; R3 1 kΩ → GND |
| Ring (R) | `HP_R` | + of C14 → APA2068 ROUT-; R4 1 kΩ → GND |
| Sleeve | `GND` |  |
| Switch | `J1_SW` | one end → GND; other → R2 → SE_BTL |

---

## Speaker connectors

| Connector | Pin 1 | Pin 2 |
|---|---|---|
| **J2** L speaker — JST PH-2 | `SPK_L_NEG` (APA2068 LOUT-) | `SPK_L_POS` (APA2068 LOUT+) |
| **J3** R speaker — JST PH-2 | `SPK_R_NEG` (APA2068 ROUT-) | `SPK_R_POS` (APA2068 ROUT+) |

---

## Power input + breakout

| Connector | Style | Pinout |
|---|---|---|
| **J4** V+ external | JST PH-2 | 1=`+5V`, 2=`GND` |
| **J5** Battery | JST PH-2 vertical (same footprint as J4) | 1=`BAT+`, 2=`GND` |
| **J6** GPIO breakout | 1×6 SIL pin header, 2.54 mm | 1=`D0`, 2=`D1_NET`, 3=`D6`, 4=`GND`, 5=`+3V3`, 6=`D5` (SD_CS moved to GPIO42 bottom pad — no jumper needed, D1 is a free breakout GPIO) |
| **J7** microSD card | Push-push microSD socket (e.g. Hirose DM3D-SF) | 8-pin SD: 1=`SD_CS` (DAT3), 2=`SD_MOSI` (CMD), 3=`GND`, 4=`+3V3`, 5=`SD_SCK` (CLK), 6=`GND`, 7=`SD_MISO` (DAT0), 8=NC (DAT1), 9=NC (DAT2) |

---

## Final BOM

### Active

| Ref | Part | Package | Library |
|---|---|---|---|
| U? | XIAO ESP32-S3 | XIAO SMD castellated | `New_Library:XIAO_ESP32-S3_SMD` |
| U2 | CS4344 | MSOP-10 (3×3 mm, 0.5 mm pitch) | `Audio:CS4344` (stock KiCad) |
| U3 | APA2068 | SOP-16-P with EP | `New_Library:SOP-16-P_3.9x9.9mm_P1.27mm_EP2.18x4.12mm` |
| U4 | TPS61023DRLR | SOT-563 (6-pin) | `New_Library:TPS61023DRLR` |

### Passives

| Ref | Value | Package | Purpose |
|---|---|---|---|
| C2 | 0.1 µF | **0402 X7R** | CS4344 VA HF |
| C3 | 1 µF | **0402 X7R** | CS4344 VA bulk |
| C4 | 10 µF | 0805 X5R | CS4344 FILT+ (size kept — 10 µF in 0402 is rare) |
| C5 | 0.1 µF | **0402 X7R** | CS4344 VQ HF |
| C6 | 3.3 µF | **0603 X5R** | CS4344 VQ popguard (down from 0805) |
| C7 | 3.3 µF | 0805 X5R | CS4344 AOUTL DC-block (audio path — keep 0805) |
| C8 | 3.3 µF | 0805 X5R | CS4344 AOUTR DC-block (audio path — keep 0805) |
| C9 | 0.1 µF | **0402 X7R** | APA2068 VDD HF (pin 10) |
| C10 | 0.1 µF | **0402 X7R** | APA2068 VDD HF (pin 15) |
| C11 | 100 µF | electrolytic 6.3 mm | APA2068 VDD bulk |
| C12 | 2.2 µF | **0603 X5R** | APA2068 BYPASS (down from 0805) |
| C13 | 220 µF | electrolytic 6.3 mm | Headphone L AC |
| C14 | 220 µF | electrolytic 6.3 mm | Headphone R AC |
| C15 | 0.1 µF | **0402 X7R** | VOLUME divider filter |
| C16 | 10 µF | 0805 X5R | Boost VIN |
| C17 | 22 µF | 0805 X5R | Boost VOUT |
| C18 | 0.1 µF | **0402 X7R** | SD card VDD decoupling (new) |
| C19 | 10 µF | 0805 X5R | SD card VDD bulk (new) |
| L1 | 4.7 µH | SMD power, 1.5 A+ | TPS61023 inductor |
| D1 | SS14 (1 A 40 V Schottky) | SMA / SOD-123FL | Boost output OR'ing diode |
| R1 | 100 kΩ | **0402** | SE/BTL pull-up |
| R2 | 100 kΩ | **0402** | SE/BTL series to jack SW |
| R3 | 1 kΩ | 0603 | HP L load reference (audio path) |
| R4 | 1 kΩ | 0603 | HP R load reference (audio path) |
| R7 | 100 kΩ | **0402** | VOLUME divider top |
| R8 | 10 kΩ | **0402** | VOLUME divider bottom |
| R9 | 365 kΩ | **0402** (1%) | Boost FB top |
| R10 | 49.9 kΩ | **0402** (1%) | Boost FB bottom |
| R11 | 10 kΩ | **0402** | SD_CS pull-up (new) |
| R12 | 10 kΩ | **0402** | SD_MOSI pull-up (new — keeps line defined when CS deasserted) |
| R13 | 10 kΩ | **0402** | SD_MISO pull-up (new) |
| ~~R14~~ | — | — | (removed — SD_CS moved to dedicated GPIO42) |
| ~~R15~~ | — | — | (removed — SD_CS moved to dedicated GPIO42) |

### Connectors

| Ref | Part |
|---|---|
| J1 | 3.5 mm stereo TRS jack with switch — PJ-320A or equivalent |
| J2 | JST PH-2 (B2B-PH-K-S or equivalent) — L speaker |
| J3 | JST PH-2 — R speaker |
| J4 | JST PH-2 — V+ external |
| J5 | JST PH-2 (B2B-PH-K-S or equivalent) — battery (was screw terminal in v1, now matches J4) |
| J6 | 1×10 male pin header, 2.54 mm pitch — GPIO breakout |

**Total:** 4 ICs + XIAO module + 6 connectors + 1 inductor + 1 diode + 16 caps + 8 resistors = **37 placements**.

---

## Net list summary

| Net | Members |
|---|---|
| `+5V` | XIAO 5V pin, J4 pin 1, D1 cathode, APA2068 pins 1/2/10/15, R1, R7, C9, C10, C11, C17, J6 pin 10 |
| `+3V3` | XIAO 3V3 pin, CS4344 pin 9, C2, C3, J6 pin 9 |
| `GND` | every return + J6 pin 8 + APA2068 EP + sleeves + screws |
| `BAT+` | XIAO BAT+ pin, J5 pin 1, U4 pin 2 (EN), U4 pin 3 (VIN), C16 |
| `BOOST_SW` | U4 pin 5, L1 (one terminal) |
| `BOOST_OUT` | U4 pin 6, L1 (other terminal), C17, D1 anode, R9 (top) |
| `FB_NET` | U4 pin 1, R9 (bottom), R10 (top) |
| `I2S_BCLK` | XIAO D7, CS4344 pin 2 |
| `I2S_LRCK` | XIAO D8, CS4344 pin 3 |
| `I2S_DOUT` | XIAO D9, CS4344 pin 1 |
| `I2S_MCLK` | XIAO D10, CS4344 pin 4 |
| `VQ_NET` | CS4344 pin 5, C5, C6 |
| `FILT_NET` | CS4344 pin 6, C4 |
| `AOUTL_AC` | CS4344 pin 7 → C7+ → C7– → APA2068 pin 6 |
| `AOUTR_AC` | CS4344 pin 10 → C8+ → C8– → APA2068 pin 3 |
| `BYPASS_C` | APA2068 pin 4, C12 |
| `VOLUME_C` | APA2068 pin 7, R7, R8, C15 |
| `SE_BTL` | APA2068 pin 13, R1, R2 |
| `J1_SW` | J1 switch contact, R2 (other side) |
| `SPK_L_NEG` | APA2068 pin 9, J2 pin 1, C13 (+) |
| `SPK_L_POS` | APA2068 pin 11, J2 pin 2 |
| `SPK_R_NEG` | APA2068 pin 16, J3 pin 1, C14 (+) |
| `SPK_R_POS` | APA2068 pin 14, J3 pin 2 |
| `HP_L` | C13 (–), J1 Tip, R3 |
| `HP_R` | C14 (–), J1 Ring, R4 |
| `D0` | XIAO pin 1 → J6 pin 1 |
| `D5` | XIAO pin 6 → J6 pin 2 |
| `D6` | XIAO pin 7 → J6 pin 3 |
| `SD_CS` | XIAO pin 2 (D1) → J7 pin 1, R11 (pull-up to +3V3) |
| `SD_SCK` | XIAO pin 3 (D2) → J7 pin 5 |
| `SD_MOSI` | XIAO pin 4 (D3) → J7 pin 2, R12 (pull-up to +3V3) |
| `SD_MISO` | XIAO pin 5 (D4) → J7 pin 7, R13 (pull-up to +3V3) |

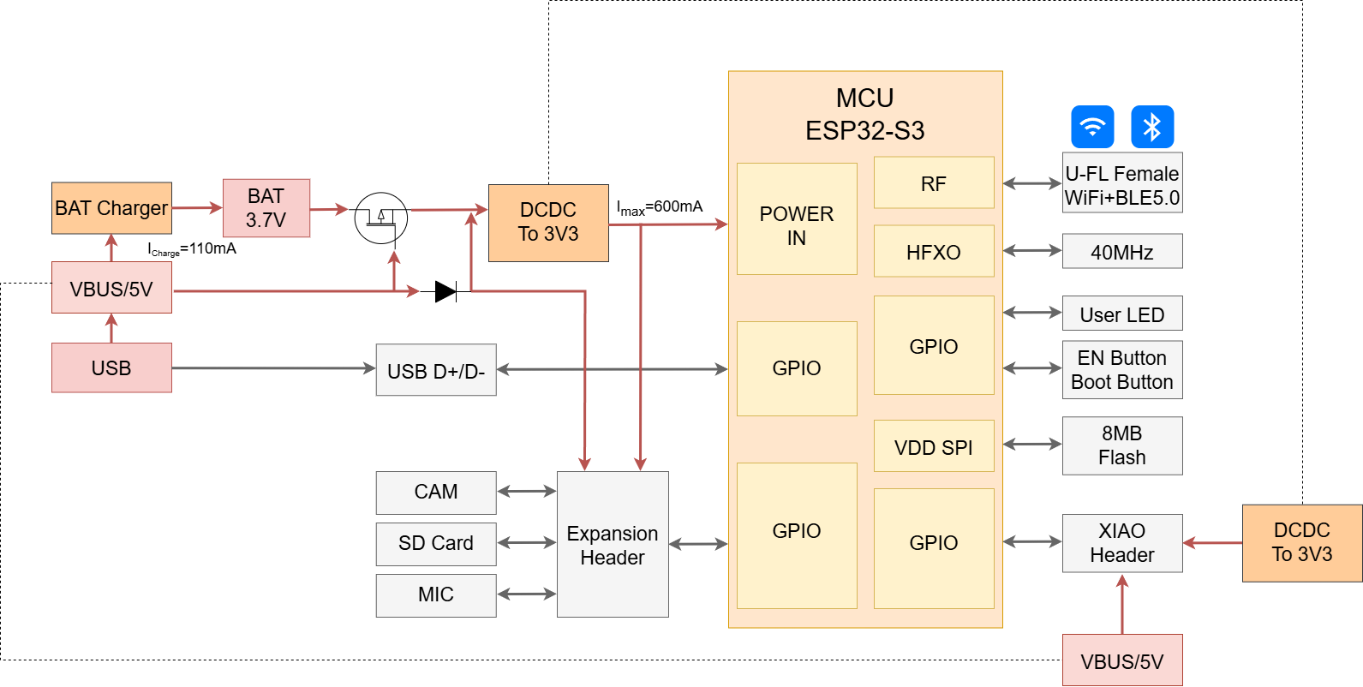
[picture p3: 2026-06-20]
main_board/datasheets/xiao_v14/202003753_XIAO ESP32S3 Sense_v1.5_SCH&PCB_260226/XIAO_ESP32S3 Sense_v1.5.drawio.png

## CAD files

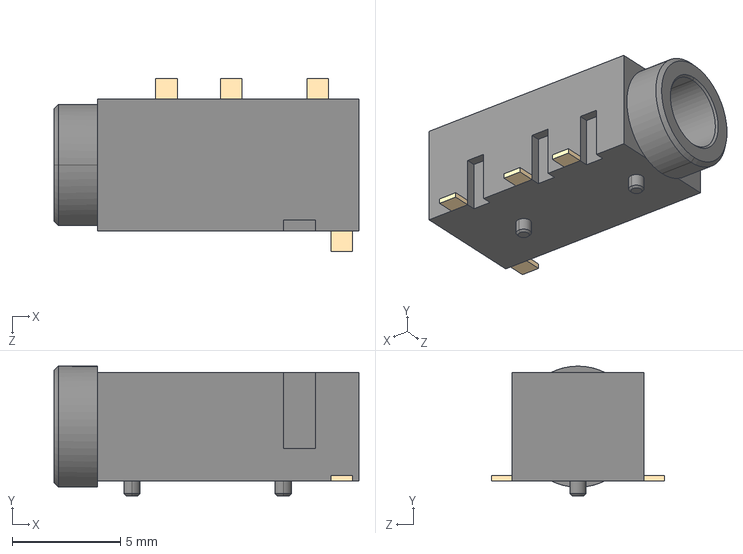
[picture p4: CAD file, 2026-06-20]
main_board/3dmodels/Jack_3.5mm_PJ-320D.step
14.1 x 6.00 x 8.00 mm

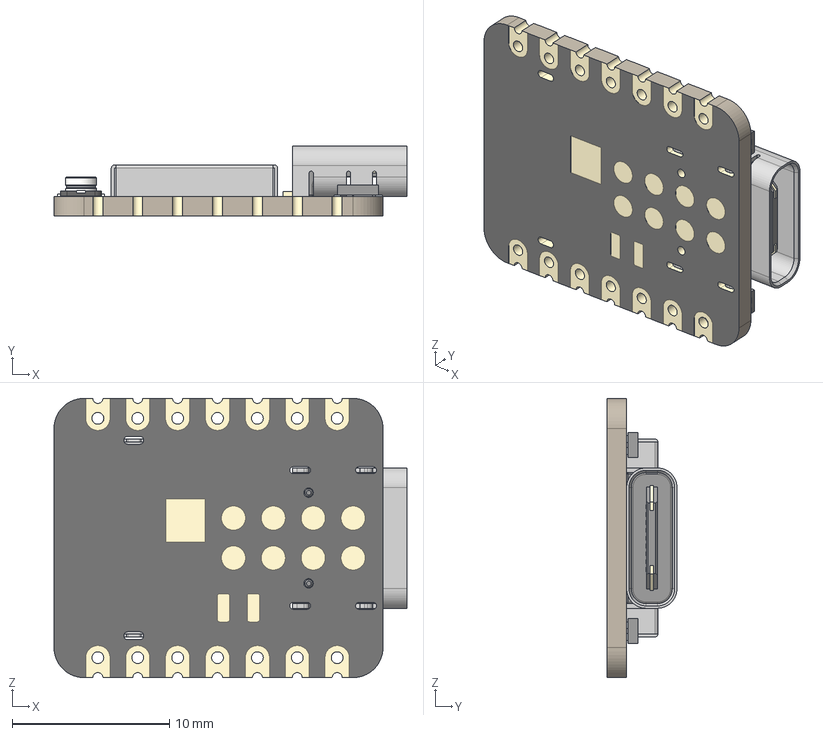
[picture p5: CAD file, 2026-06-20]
main_board/3dmodels/XIAO-ESP32S3.step
22.5 x 4.46 x 17.8 mm
BOSS-EXTRUDE14_8_
BOSS-EXTRUDE7_4_
BOSS-EXTRUDE7_3_
BOSS-EXTRUDE14_4_
BOSS-EXTRUDE14_2_
BOSS-EXTRUDE14_11_
BOSS-EXTRUDE7_7_
BOSS-EXTRUDE14_9_
BOSS-EXTRUDE14_3_
BOSS-EXTRUDE14_7_
MIRROR2
BOSS-EXTRUDE14_5_
BOSS-EXTRUDE14_12_
BOSS-EXTRUDE7_8_
BOSS-EXTRUDE7_1_
BOSS-EXTRUDE14_10_
BOSS-EXTRUDE7_9_
BOSS-EXTRUDE14_6_
BOSS-EXTRUDE14_1_
BOSS-EXTRUDE7_6_
BOSS-EXTRUDE7_2_
CUT-EXTRUDE5
BOSS-EXTRUDE7_5_
Shield
Pins x 2
U.FL-R-SMT-1_10_ v1

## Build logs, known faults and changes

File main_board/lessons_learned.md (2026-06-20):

# esp32audio v1 — lessons learned

What went well, what went wrong, what to do differently next time.
Captured during the v1 build so v2 (and any other KiCad-via-MCP project)
benefits.

---

## 1. Schematic phase

### What worked

- **Build plan in markdown before touching KiCad.** The 300-line plan
  (`project_plan.md`) made the schematic step almost mechanical — every
  decision (DAC choice, mount style, dividers, fb resistors, jack pinout)
  was already locked. Net list, BOM, and pin tables in the plan mapped
  1:1 to MCP calls.
- **Custom symbols already existed** (XIAO, APA2068, TPS61023 in
  `New_Library`). Saved an hour vs. authoring them.
- **`snap_to_grid` after placement.** Off-grid components produce
  unconnected-pin ERC noise. Running `snap_to_grid` with all elements
  before wiring fixed a lot of issues in one call.

### What didn't

- **PWR_FLAG on a rail that already has `power_out`** triggers an ERC
  error (two power-out pins shorted). XIAO 3V3 pin is `power_out`, so
  adding a PWR_FLAG on +3V3 was wrong. Only add PWR_FLAG on nets whose
  source is a `power_in` pin (like XIAO 5V / BAT+).
- **Hidden EP pin on APA2068**: pin 17 (EP) is hidden in the symbol.
  `batch_connect` silently skipped it. The schematic appeared clean
  but the EP wasn't grounded at the PCB level — fixed only during PCB
  cleanup by setting the EP pad's net directly via pcbnew.
- **Symbol pin names vs footprint pad names mismatch**:
  `AudioJack3_Switch` symbol uses pins `T/R/S/TN/RN/SN`. No stock
  KiCad footprint has matching pad names — they use `T/S/R1/R2/R1N`
  etc. The schematic looks right, the PCB connects via different pad
  names. **Always verify symbol pin names == footprint pad names
  before sync.** Use `list_symbol_pins` and `get_footprint_info` to
  cross-check.

### Rule for v2

> Before sync_schematic_to_board, for every component verify that
> `symbol.pin_name` set == `footprint.pad_name` set. Mismatch =
> unconnected pads.

---

## 2. PCB placement phase

### What worked

- **`check_courtyard_overlaps` with `include_boundary=True`** caught
  90% of placement problems early. Run it after every batch of moves.
- **Two-sided component placement** worked — XIAO on top, ICs on
  bottom (under XIAO), small passives on bottom. The 50×42mm board
  fits 36 footprints comfortably.
- **`add_board_outline` with rounded_rectangle** is the right
  primitive (KiCad UI's outline tool is finicky).

### What didn't

- **`add_board_outline` called multiple times stacks outlines** —
  doesn't replace. Caused `invalid_outline ×5` + `copper_edge_clearance
  ×77` DRC violations. Three boards (42×32 + 50×42 + 50×42) all on
  Edge.Cuts at once.

  **Fix in v2**: Before changing board outline, programmatically
  remove all existing Edge.Cuts drawings first (no MCP tool for this
  — needs pcbnew script).

- **Courtyards include silkscreen/USB-C overhang**. XIAO bbox is
  20.9×26.1mm but the body is only 21×17.5mm. The `overlap` check
  flags things that are physically fine (top vs bottom, courtyard
  fluff). **Treat overlaps as a starting point for visual check, not
  a strict failure list.**

- **Auto-save races between MCP and pcbnew scripts**: writing the
  board via Python while MCP has it open → "auto-save refused, disk
  changed externally". Always reload via `open_project` after a
  Python script writes the board.

### Rule for v2

> When working with custom Python scripts that write `.kicad_pcb`,
> always:
> 1. Save / close the board in MCP (or accept the auto-save warning)
> 2. Run the Python script
> 3. `open_project` to reload the MCP's view of the board
> 4. Then continue MCP edits

---

## 3. Routing phase

### What worked

- **Manual `route_pad_to_pad` for the critical 10–15 nets**
  (boost loop, audio chain, GND vias for EP). Fast, precise, no
  surprises.
- **Freerouting via `java -jar freerouting.jar -de in.dsn -do out.ses`**
  routed 47/57 nets in 1 minute and eliminated all 35 tracks-crossing
  errors. The MCP's `import_ses` then loaded results cleanly.
- **`add_gnd_stitching_vias` strategy combo** (`grid + around_refs +
  in_zones`) placed 92 stitching vias with collision checking.

### What didn't

- **Manual routing AFTER Freerouting created crossings** that
  Freerouting had avoided. Order matters: run Freerouting LAST, then
  only touch up if needed. Or: rip up everything, re-run Freerouting
  with the new constraints.

- **`route_pad_to_pad` doesn't avoid existing traces**. It draws a
  fresh Manhattan path. If the path crosses other traces, you get
  shorts. There's no "interactive router" equivalent in the MCP.

- **`add_gnd_stitching_vias` with 4mm spacing in a tiny board** added
  92 vias and made the bottom pour MORE fragmented (16 islands vs the
  original 10). The pour breaks around each via cluster. **Smaller
  boards need fewer stitches, not more.** For a 50×42mm board, 20–40
  stitching vias is plenty; 92 is over-engineering.

- **Edge-clearance violations from stitching vias near board edge**.
  The tool's `edgeMargin=0.5mm` parameter wasn't tight enough vs the
  DRC's 0.5mm edge clearance — vias at 0.65mm from edge with 0.3mm
  radius leave 0.35mm to edge, below 0.5mm. **Set edgeMargin to >=
  required_clearance + via_radius** (so 0.5 + 0.3 = 0.8mm minimum).

### Rule for v2

> Routing order:
> 1. Set design rules and net classes first (NOT after routing)
> 2. Run Freerouting once on full unrouted board
> 3. Manually patch unrouted nets if any
> 4. Add stitching vias LAST, in small dose (20–30 for board < 2500 mm²)
> 5. Re-run DRC; only then iterate

---

## 4. MCP tooling

### Strengths

- Add primitives (place, route, copper pour, via): excellent
- Inspection (component list, pads, overlaps, DRC): excellent
- Analyzer integration (schematic, PCB, EMC, cross): excellent —
  catches issues no naive DRC pass would
- Batch operations (`batch_add_components`, `batch_connect`): saved
  hundreds of single-shot calls

### Gaps that bit us

| Need | Workaround |
|---|---|
| Delete graphic items (Edge.Cuts lines) | pcbnew Python script |
| Delete vias by criteria (edge dist, dup) | pcbnew Python script |
| Set pad net assignment (e.g. EP to GND) | pcbnew Python script |
| Move silk text (refs to F.Fab to declutter) | pcbnew Python script |
| Push-and-shove router | Use Freerouting via Java |
| Connection-aware re-route | Rip up + Freerouting |
| Add net classes | Edit `.kicad_pro` directly |

**Pattern**: when MCP doesn't expose a primitive, **pcbnew (KiCad's
Python module) does**. The bundled Python interpreter at
`/Applications/KiCad/KiCad.app/Contents/Frameworks/Python.framework/Versions/Current/bin/python3`
has `pcbnew` import-able with full SWIG bindings.

### Rule for v2

> When MCP runs out of primitives, write a 30-line pcbnew Python
> script. Don't try to brute-force it via 50 MCP calls.

---

## 5. Freerouting setup

### Install in 3 minutes

```bash
brew install openjdk
mkdir -p ~/.kicad-mcp
curl -L -o ~/.kicad-mcp/freerouting.jar \
  "https://github.com/freerouting/freerouting/releases/download/v2.2.4/freerouting-2.2.4.jar"
```

### Run

```bash
cd <project>
/opt/homebrew/opt/openjdk/bin/java -jar ~/.kicad-mcp/freerouting.jar \
    -de board.dsn -do board.ses -mp 200 -us global
```

`-mp N` = max passes (200 = thorough), `-us global` = global optimisation.

### Gotchas

- The MCP `check_freerouting` tool looks at `/usr/bin/java` only.
  Without `sudo ln -sfn` to symlink the JDK into
  `/Library/Java/JavaVirtualMachines/`, the MCP autoroute won't see
  Java. Workaround: run Freerouting from Python with the explicit
  brewed Java path.
- Freerouting needs the board fully exported (no in-progress traces)
  for best results. Always rip-up first if you re-run.

---

## 6. Design choices we'd revisit

| Decision | What we'd change |
|---|---|
| 0603 / 0805 passives | Consider 0402 for digital decoupling — saves ~25–30 mm² total |
| PJ-320 audio jack symbol | Use a symbol whose pin names match a stock footprint (or author a custom symbol/footprint pair upfront) |
| 92 GND stitching vias | 25–35 is plenty for a 50×42mm board; more fragments the pour |
| 0.5mm edge clearance | Keep. PCBWay's 0.3mm min is too aggressive for hand-assembly boards |
| 50×42mm board | Could shrink to ~45×38mm with 0402 passives, but at the cost of routing density and hand assembly |
| Manual routing after Freerouting | Don't. Always rip-up first if iterating |

---

## 7. Workflow that worked

For v2 (or any new MCP-based KiCad project):

```
1. PLAN
   - Write project_plan.md with all design decisions, BOM, net list
   - Write pcb_plan.md with floor plan, top/bottom assignments, DRC

2. SCHEMATIC
   - kicad_sch_edit skill
   - Verify all symbol pin names against footprint pad names BEFORE sync
   - Skip PWR_FLAG on nets that have a power_out pin
   - Annotate, snap to grid, run ERC

3. PCB SETUP
   - Set design rules ONCE (for target fab, e.g. PCBWay)
   - Write .kicad_dru with net-class rules
   - sync_schematic_to_board
   - Place components per pcb_plan.md
   - Verify with check_courtyard_overlaps

4. ROUTE
   - Export DSN -> Freerouting -> import SES
   - Manually patch any unrouted nets
   - Add 20-30 GND stitching vias (NOT 100)
   - Refill zones, run DRC

5. CLEANUP (pcbnew Python script)
   - Set EP pads to GND
   - Move ref text to F.Fab, hide values
   - Remove edge-clearance vias

6. VALIDATE
   - kicad-happy skill: schematic + pcb + cross + EMC
   - Fix HIGH findings (real blockers, not heuristic noise)
   - Document false positives (VM-001 5V/3.3V on I2S etc.)

7. SHIP
   - Export gerbers + drill + CPL + BOM
   - Order from PCBWay (or fab of choice)
```

Total expected hours: ~6–8 for a board this size if you don't have
to iterate the schematic.

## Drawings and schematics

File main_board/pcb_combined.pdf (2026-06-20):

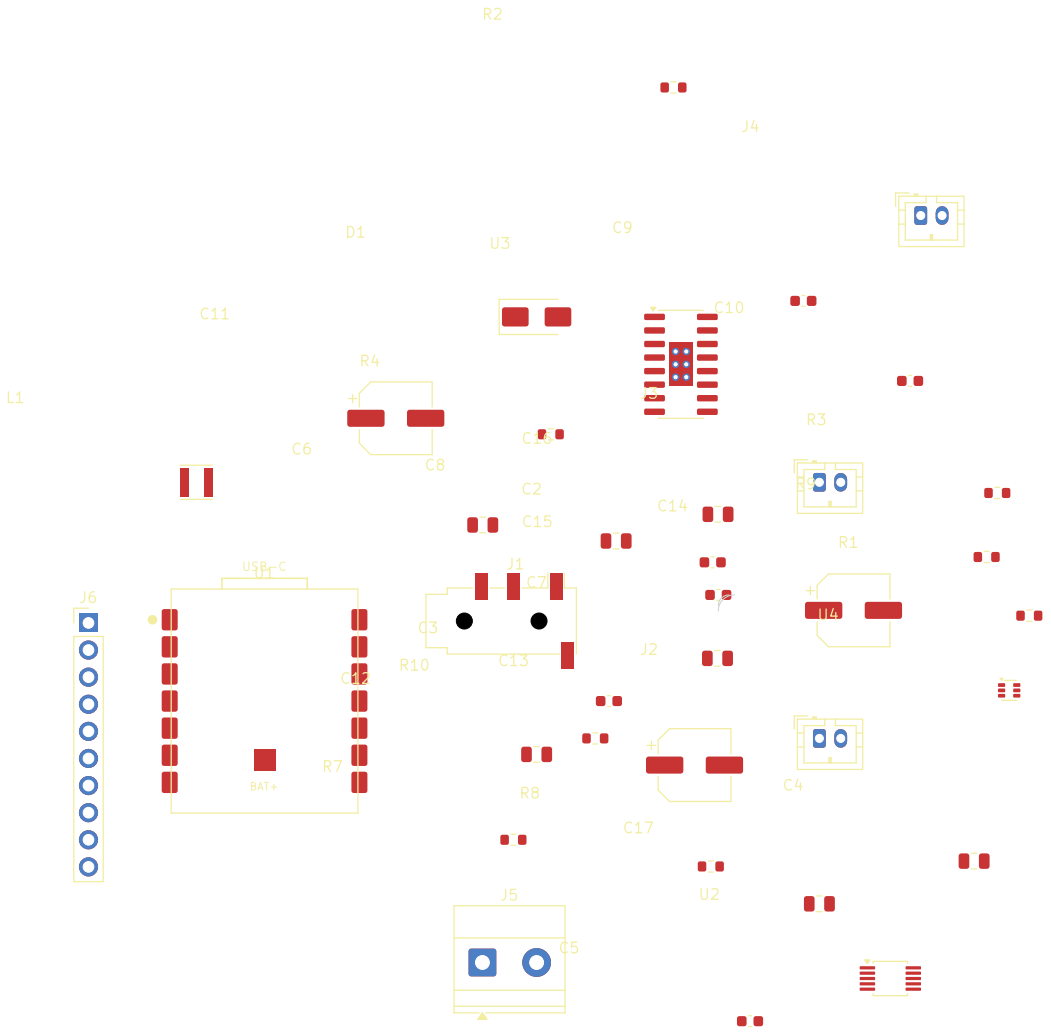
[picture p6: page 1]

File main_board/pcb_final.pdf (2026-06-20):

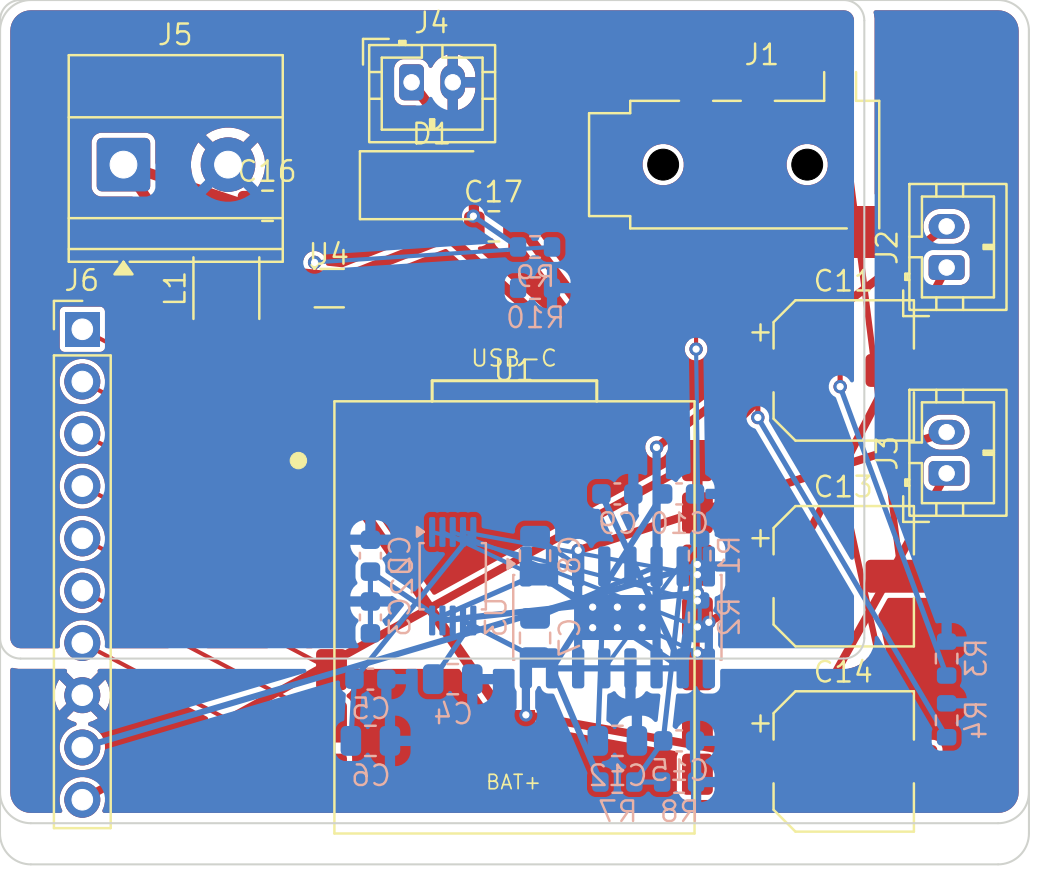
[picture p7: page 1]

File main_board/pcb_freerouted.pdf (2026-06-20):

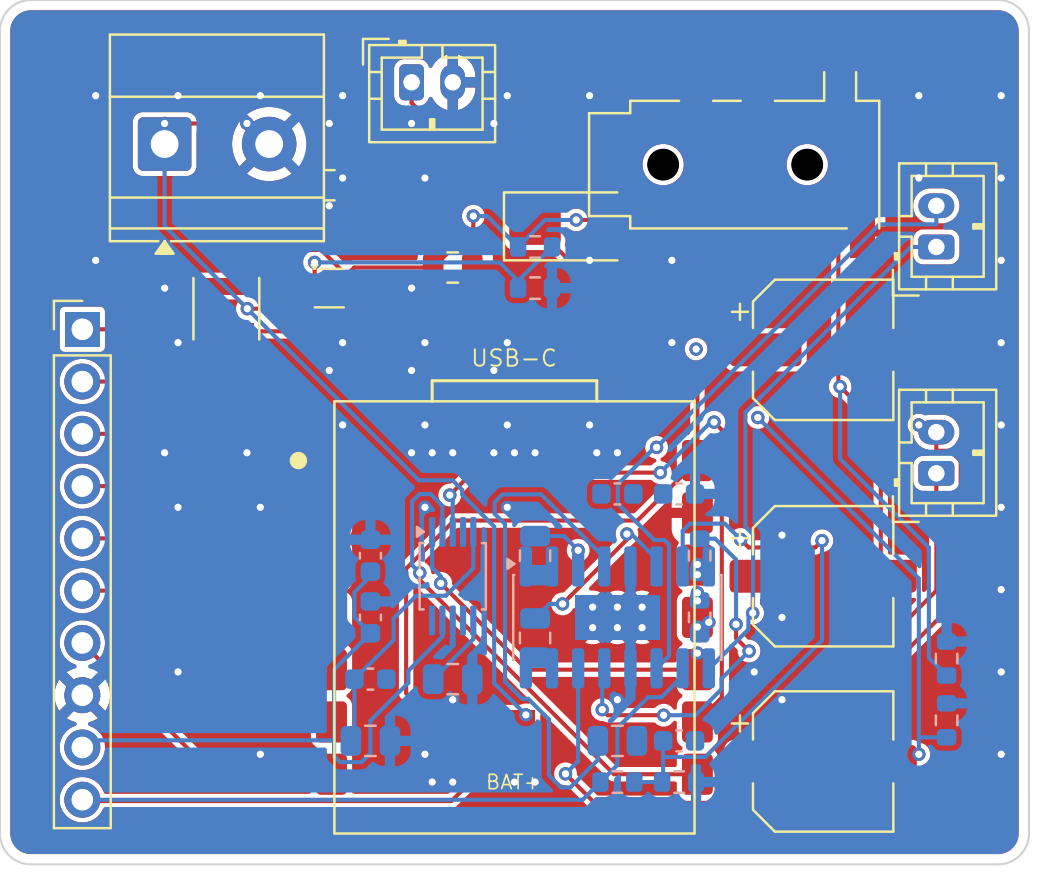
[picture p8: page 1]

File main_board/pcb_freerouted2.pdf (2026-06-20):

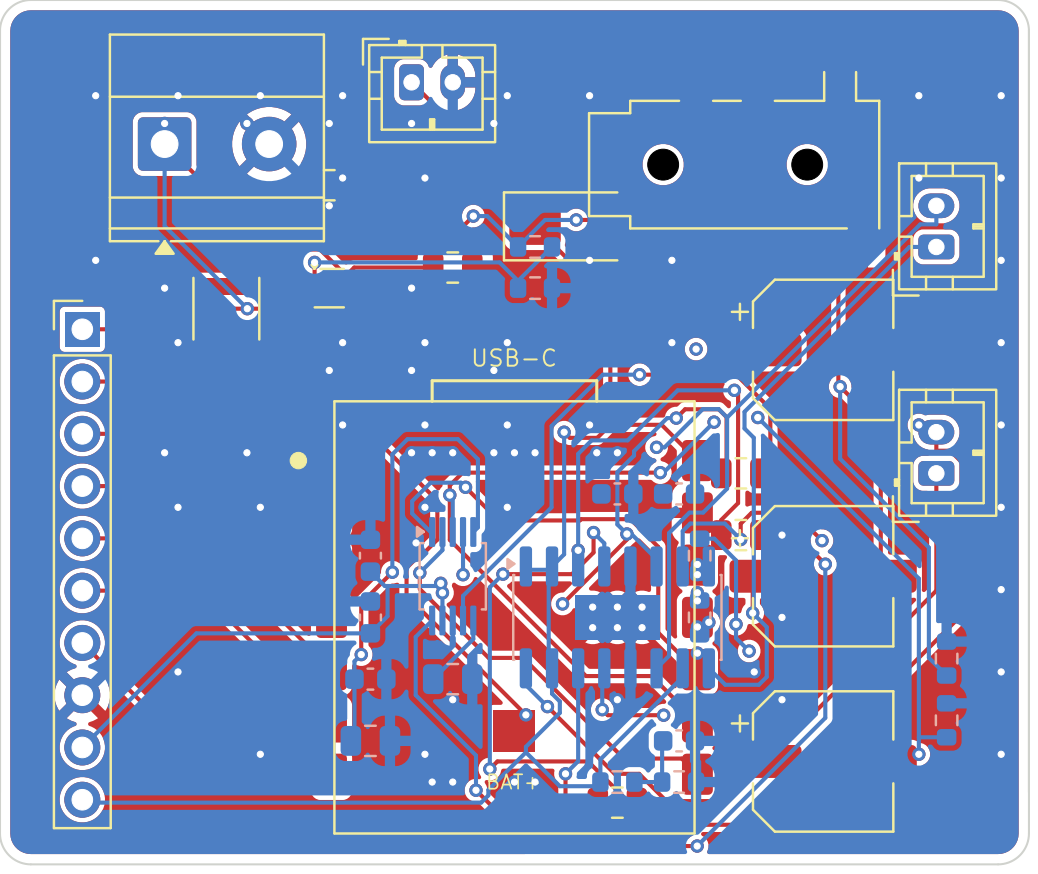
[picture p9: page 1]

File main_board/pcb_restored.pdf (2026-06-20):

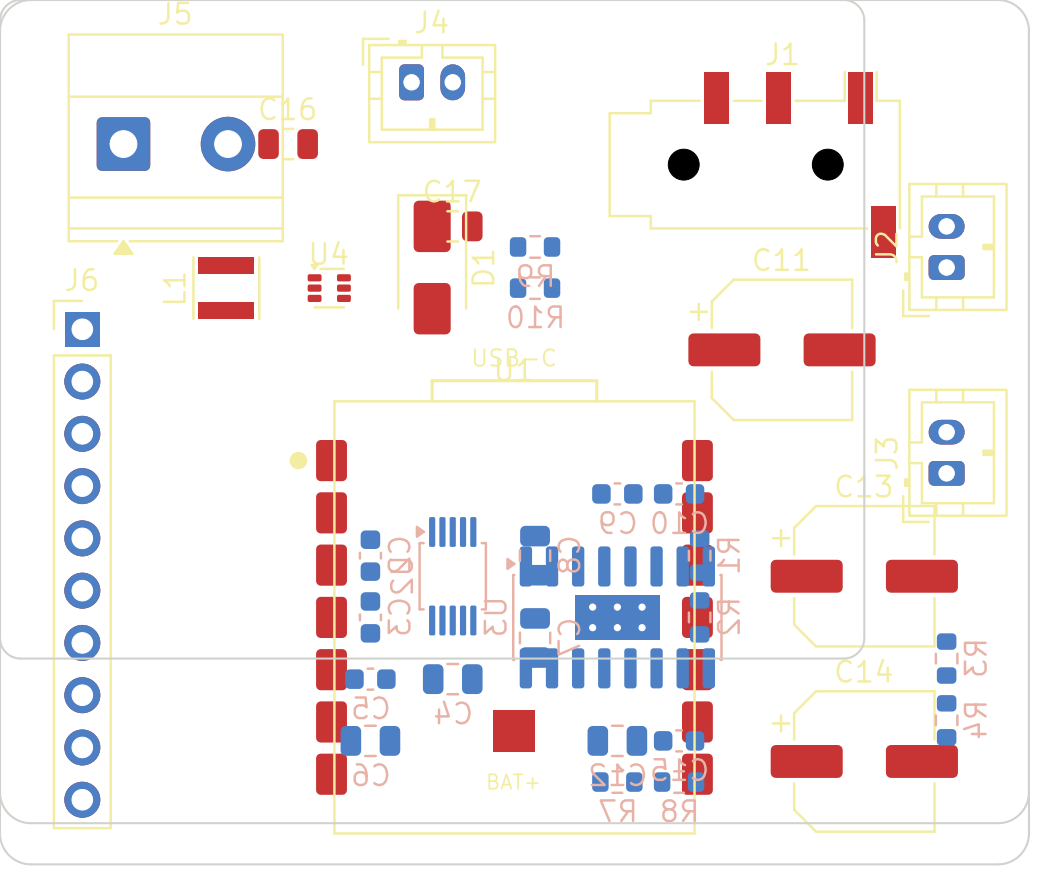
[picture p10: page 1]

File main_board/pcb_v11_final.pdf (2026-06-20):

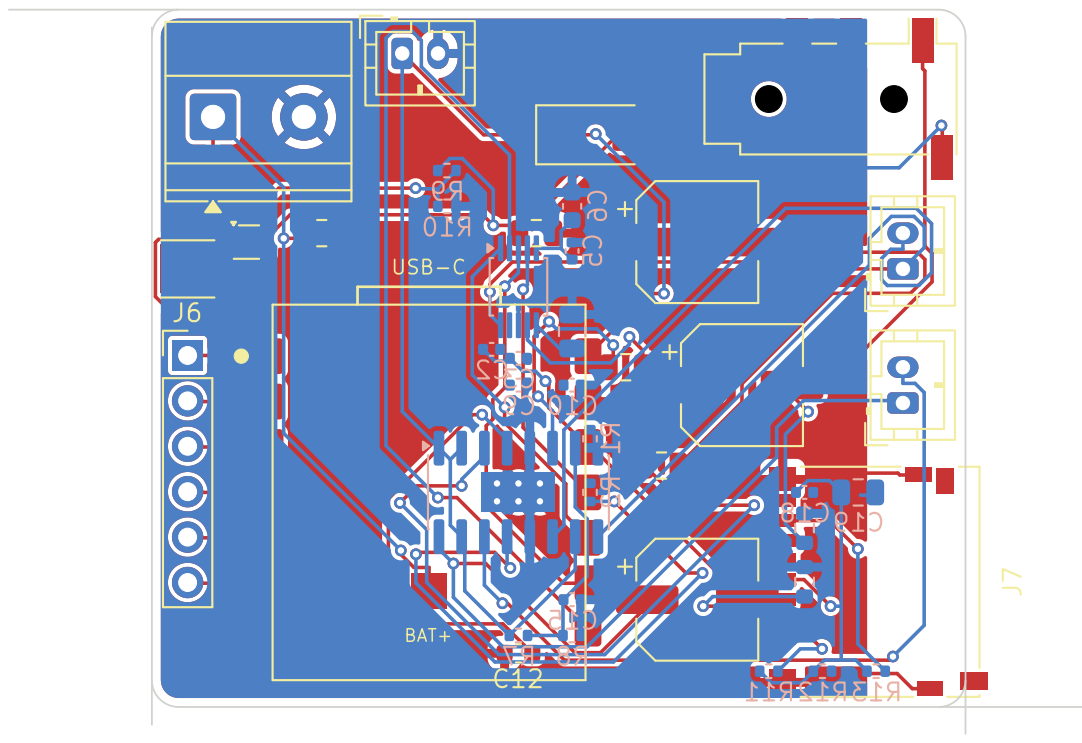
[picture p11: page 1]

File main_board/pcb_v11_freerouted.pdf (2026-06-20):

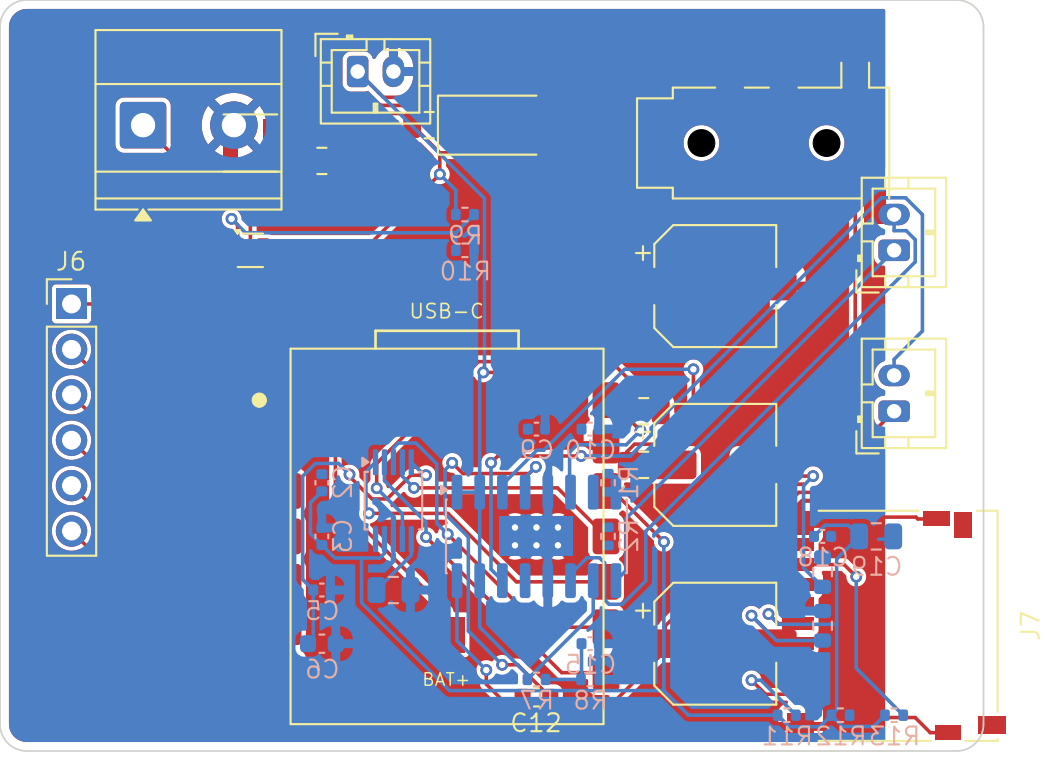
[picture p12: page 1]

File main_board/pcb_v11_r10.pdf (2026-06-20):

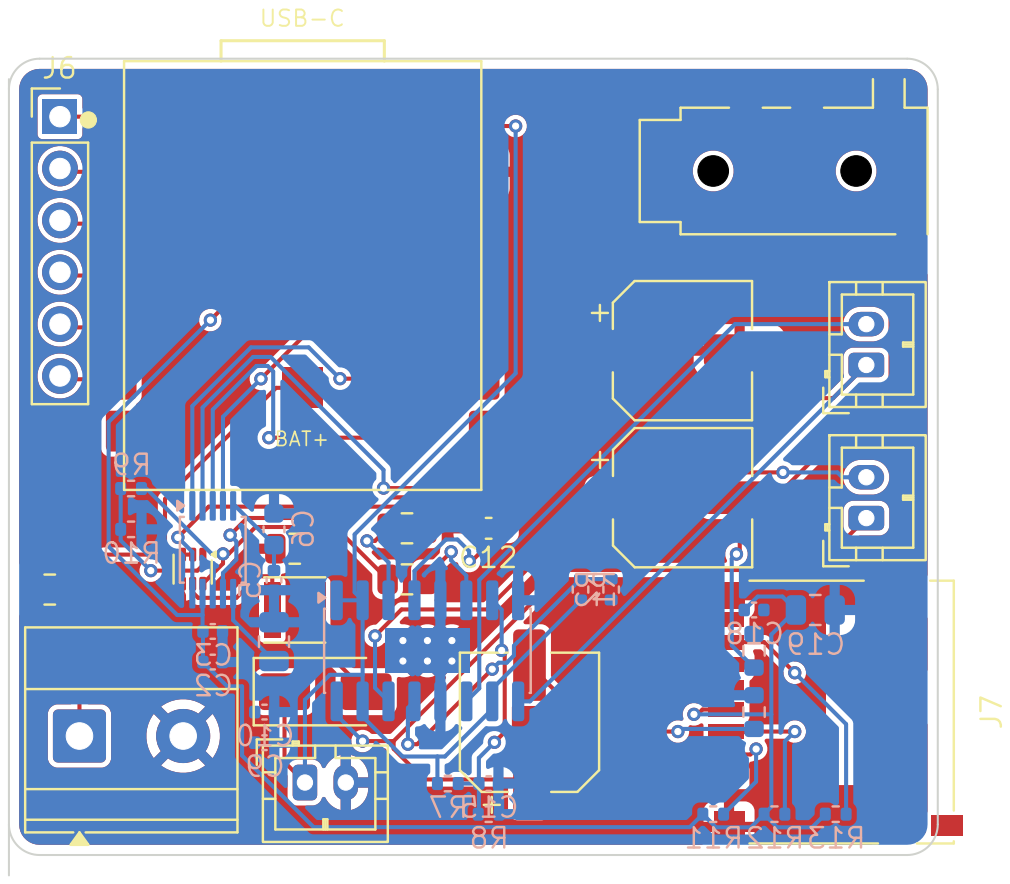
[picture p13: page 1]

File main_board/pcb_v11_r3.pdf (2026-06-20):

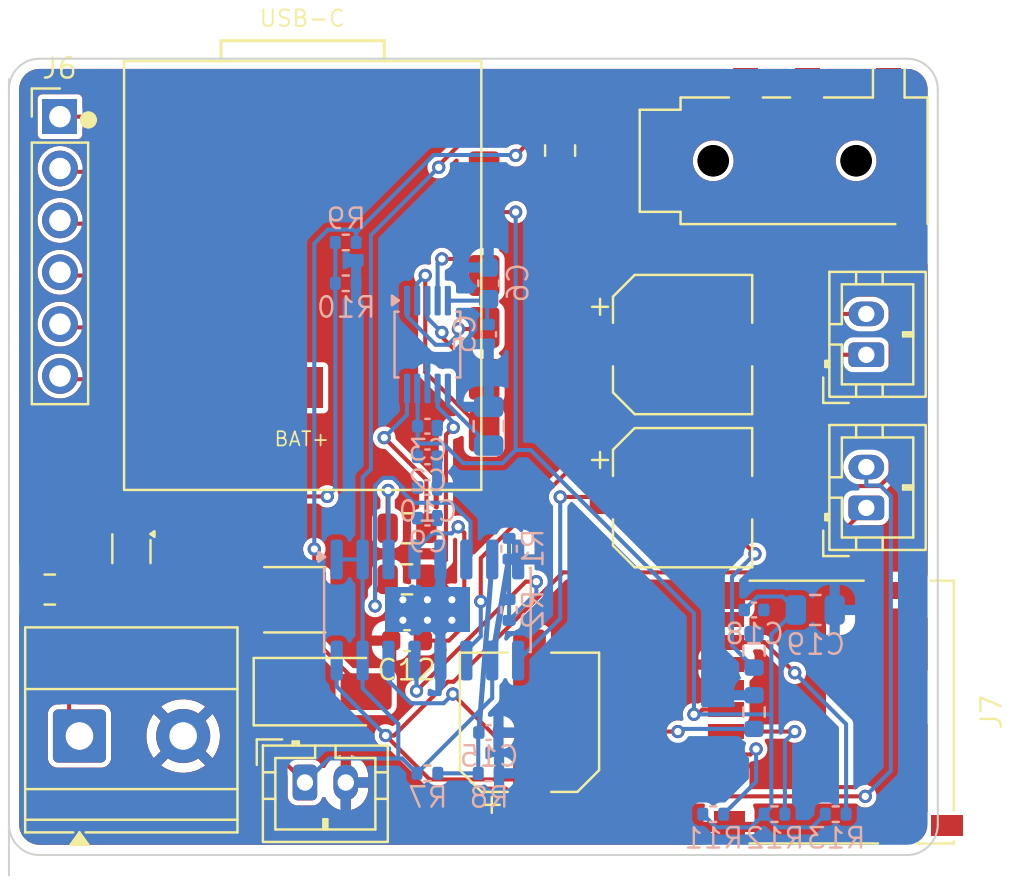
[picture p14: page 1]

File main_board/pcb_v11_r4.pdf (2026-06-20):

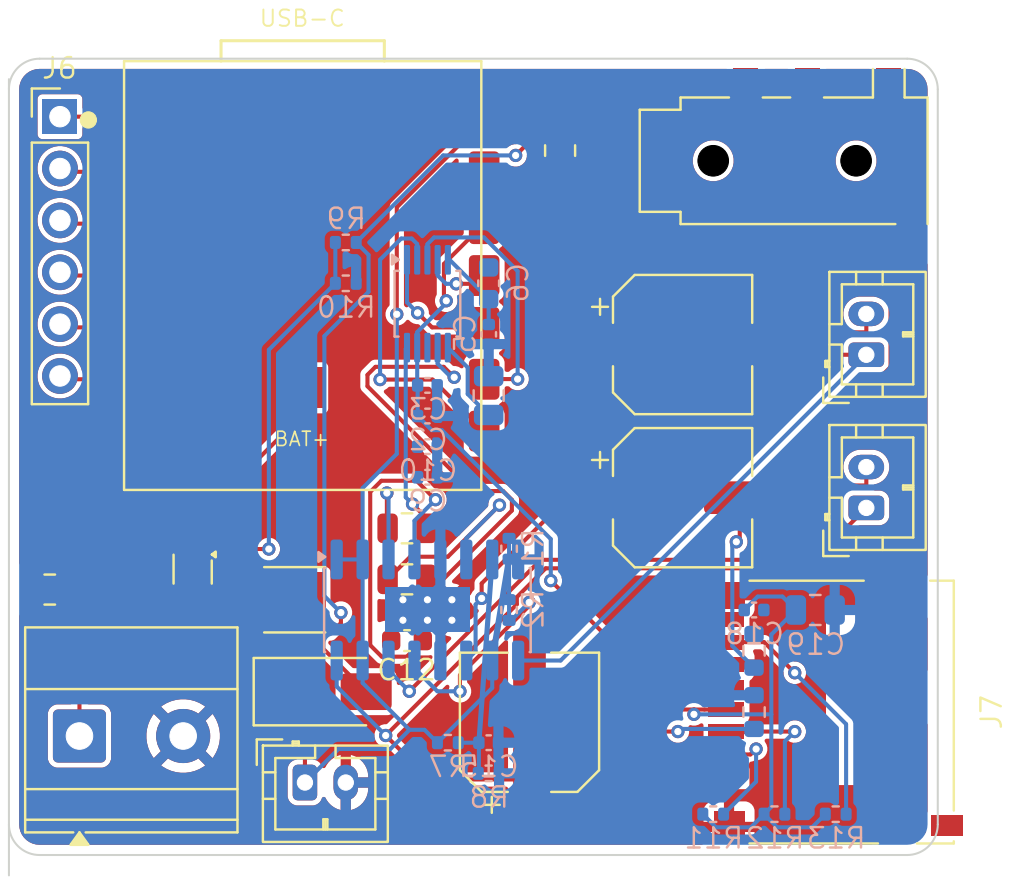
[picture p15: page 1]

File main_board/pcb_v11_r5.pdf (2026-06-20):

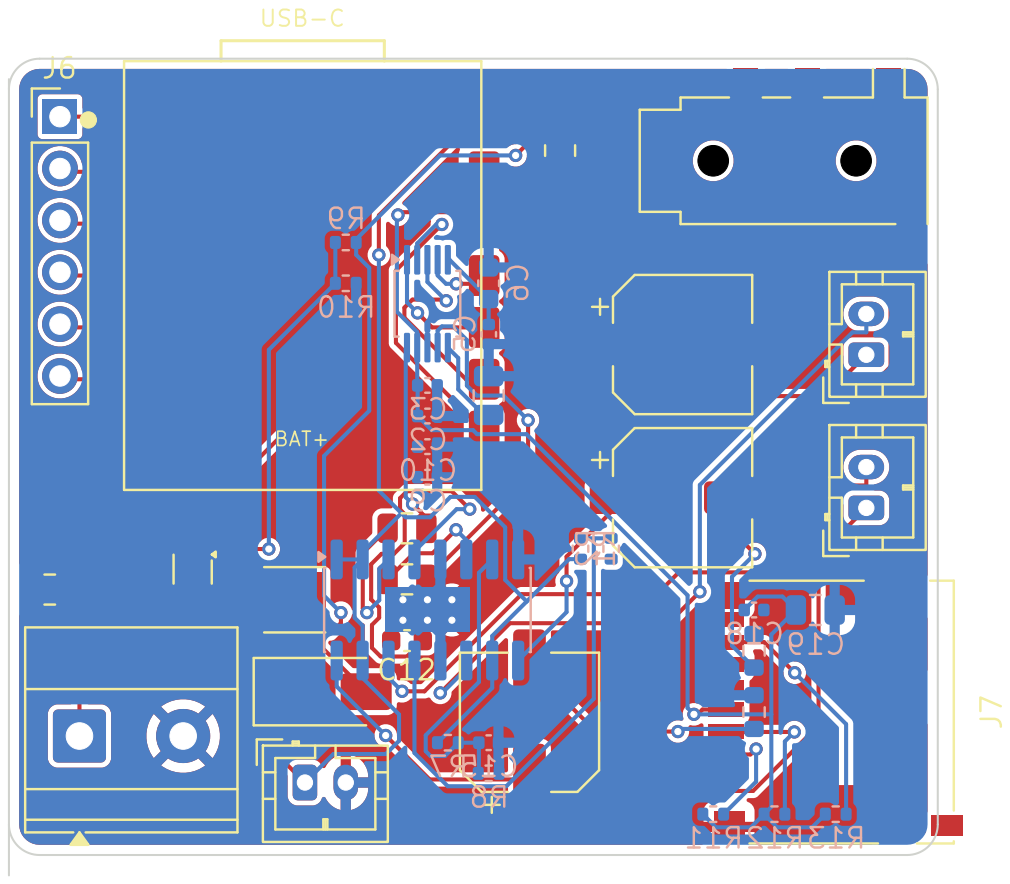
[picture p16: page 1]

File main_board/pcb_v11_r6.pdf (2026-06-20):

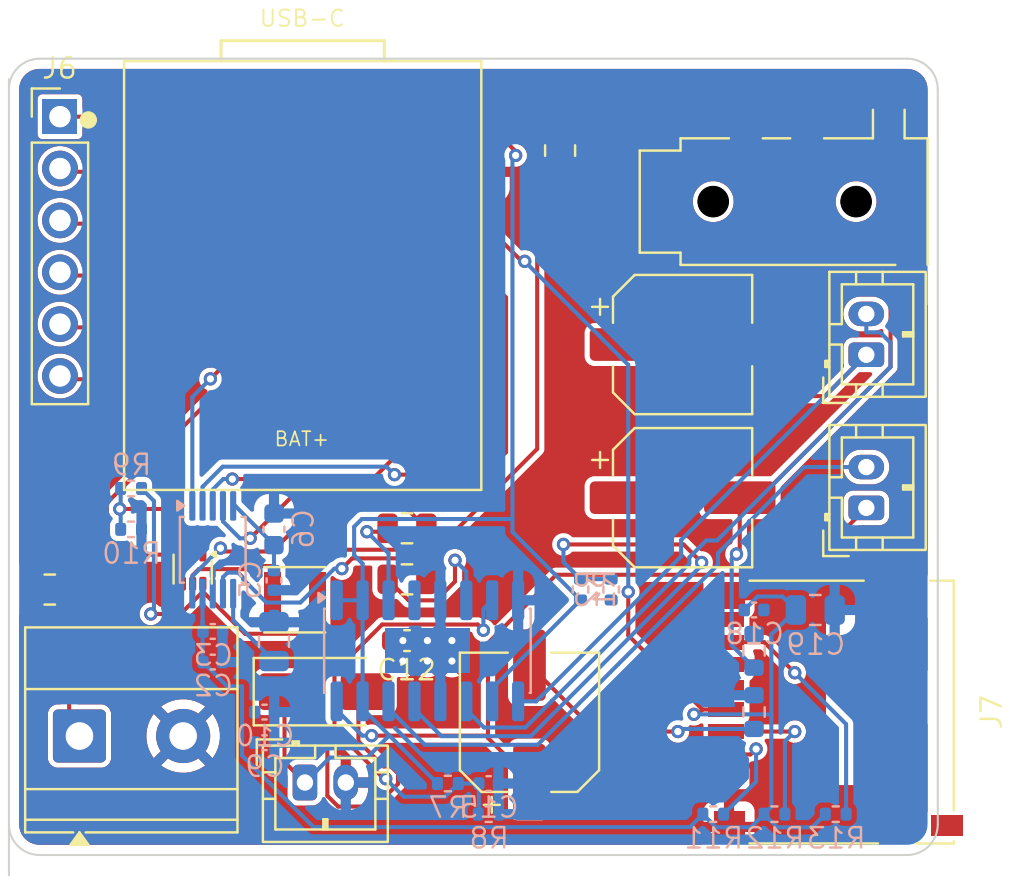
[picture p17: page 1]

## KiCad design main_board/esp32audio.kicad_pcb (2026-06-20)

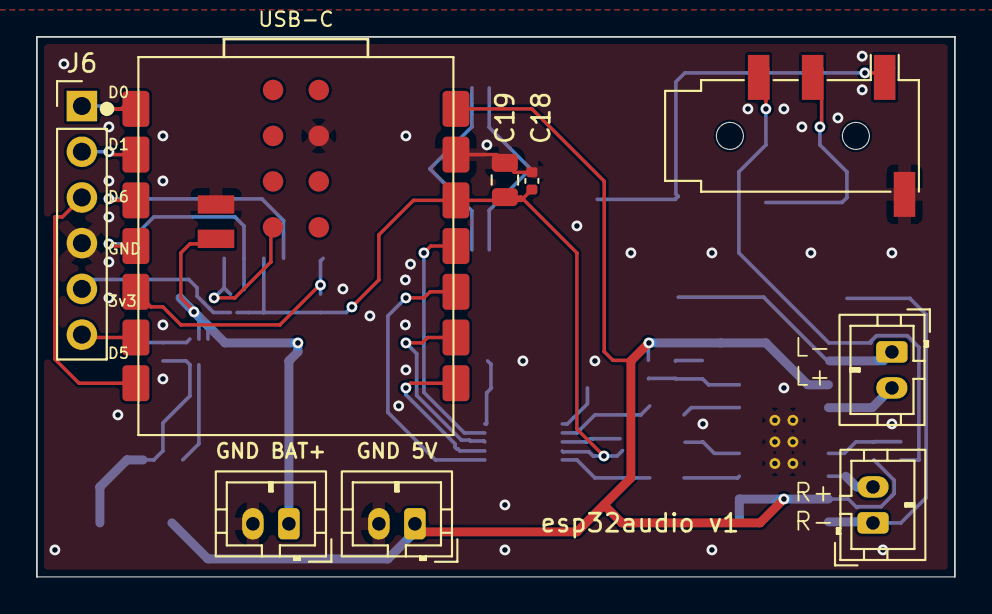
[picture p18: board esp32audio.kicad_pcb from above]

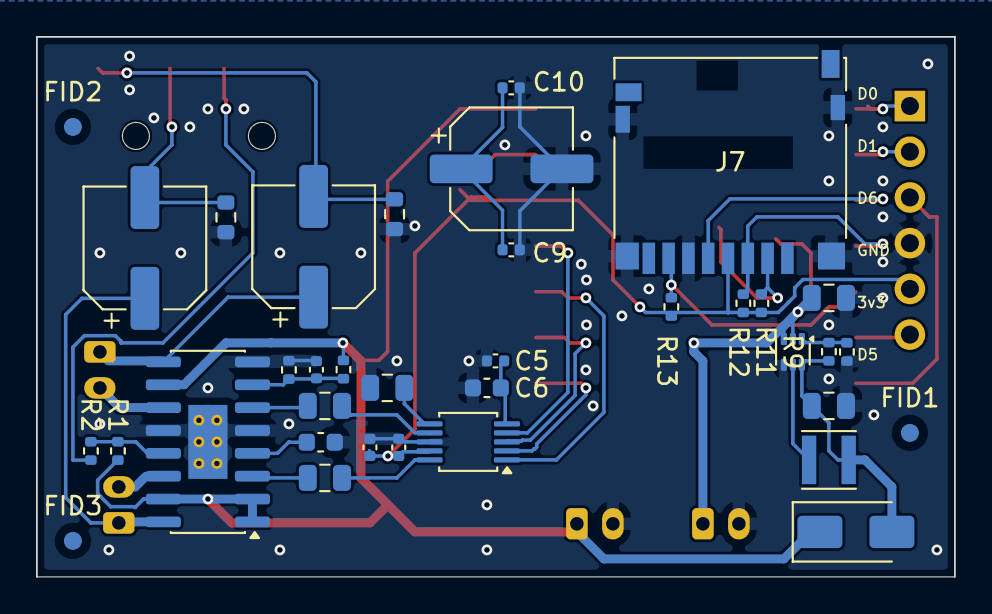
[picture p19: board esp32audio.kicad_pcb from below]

Board: 2 copper layers, 51.0 x 30.0 mm, 45 parts (36 on the bottom side), 35 nets.

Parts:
C2, C5, C9, C10, C15, C18: 0.1uF; C_0402_1005Metric
C3: 1uF; C_0402_1005Metric
C4, C16, C19: 10uF; C_0805_2012Metric
C6: 3.3uF; C_0603_1608Metric
C7, C8: 3.3uF; C_0805_2012Metric
C11: 100uF; CP_Elec_6.3x5.4
C12: 2.2uF; C_0603_1608Metric
C13, C14: 220uF; CP_Elec_6.3x5.4
C17: 22uF; C_0805_2012Metric
D1: SS14; D_SMA
FID1, FID2, FID3: Fiducial; Fiducial_1mm_Mask2mm
GND 5V: V+_EXT; JST_PH_B2B-PH-K_1x02_P2.00mm_Vertical
GND BAT+: BATTERY; JST_PH_B2B-PH-K_1x02_P2.00mm_Vertical
J1: PJ-320A; Jack_3.5mm_PJ320D_Horizontal
J2: L_SPKR; JST_PH_B2B-PH-K_1x02_P2.00mm_Vertical
J3: R_SPKR; JST_PH_B2B-PH-K_1x02_P2.00mm_Vertical
J6: GPIO_BREAKOUT; PinHeader_1x06_P2.54mm_Vertical
J7: microSD; microSD_HC_Hirose_DM3D-SF
L1: 4.7uH; L_Taiyo-Yuden_NR-30xx
R1, R2, R7: 100k; R_0402_1005Metric
R3, R4: 1k; R_0603_1608Metric
R8, R11, R12, R13: 10k; R_0402_1005Metric
R9: 365k; R_0402_1005Metric
R10: 49.9k; R_0402_1005Metric
U1: XIAO ESP32-S3; XIAO_ESP32-S3_SMD
U2: CS4344; TSSOP-10_3x3mm_P0.5mm
U3: APA2068; SOP-16-P_3.9x9.9mm_P1.27mm_EP2.18x4.12mm
U4: TPS61023DRLR; SOT-563

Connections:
/+3V3: C2.1, C3.1, C18.1, C19.1, J6.5, J7.4 (VDD), R11.1, R12.1, R13.1, U1.12 (3V3), U2.9 (VA)
/+5V: D1.1 (K), GND 5V.1, R1.1, R7.1, U1.14 (5V), U3.1 (~MUTE), U3.2 (~SHUTDOWN), U3.10 (VDD), U3.15 (VDD)
/AOUTL_AC: C7.2, U3.6 (LIN-)
/AOUTL_RAW: C7.1, U2.7 (AOUTL)
/AOUTR_AC: C8.2, U3.3 (RIN-)
/AOUTR_RAW: C8.1, U2.10 (AOUTR)
/BAT+: C16.1, GND BAT+.1, U1.15 (BAT+), U4.2 (EN), U4.3 (VIN)
/BOOST_OUT: C17.1, D1.2 (A), L1.2, R9.1, U4.6 (VOUT)
/BOOST_SW: L1.1, U4.5 (SW)
/BYPASS_C: C12.1, U3.4 (BYPASS)
/D0: J6.1, U1.1 (D0/GPIO1)
/D1_NET: J6.2, U1.2 (D1/GPIO2)
/D5_NET: J6.6, U1.6 (D5/GPIO6)
/D6_NET: J6.3, U1.7 (D6/GPIO43)
/FB_NET: R9.2, R10.1, U4.1 (FB)
/FILT_NET: C4.1, U2.6 (FILT+)
/GND: C2.2, C3.2, C4.2, C5.2, C6.2, C9.2, C10.2, C11.2, C12.2, C15.2, C16.2, C17.2, C18.2, C19.2, GND 5V.2, GND BAT+.2, J1.S, J6.4, J7.6 (VSS), J7.SH (SHIELD), R3.2, R4.2, R8.2, R10.2, U1.13 (GND), U1.16 (GND_BTM), U1.17 (GND_TP1), U2.8 (GND), U3.5 (GND), U3.8 (VOLMAX), U3.12 (GND), U3.17 (EP), U4.4 (GND)
/HP_L: C13.2, J1.T, R3.1
/HP_R: C14.2, R4.1
/I2S_BCLK: U1.8 (D7/GPIO44), U2.2 (~DEM/SCLK)
/I2S_DOUT: U1.10 (D9/GPIO8), U2.1 (SDIN)
/I2S_LRCK: U1.9 (D8/GPIO7), U2.3 (LRCK)
/I2S_MCLK: U1.11 (D10/GPIO9), U2.4 (MCLK)
/SD_CS: J7.2 (DAT3/CD), R11.2, U1.23 (USB_D-)
/SD_MISO: J7.7 (DAT0), R13.2, U1.5 (D4/GPIO5)
/SD_MOSI: J7.3 (CMD), R12.2, U1.4 (D3/GPIO4)
/SD_SCK: J7.5 (CLK), U1.3 (D2/GPIO3)
/SE_BTL: R1.2, R2.1, U3.13 (SE/~BTL)
/SPK_L_NEG: C13.1, J2.1, U3.9 (LOUT-)
/SPK_L_POS: J2.2, U3.11 (LOUT+)
/SPK_R_NEG: C14.1, J3.1, U3.16 (ROUT-)
/SPK_R_POS: J3.2, U3.14 (ROUT+)
/VOLUME_C: C15.1, R7.2, R8.1, U3.7 (VOLUME)
/VQ_NET: C5.1, C6.1, U2.5 (VQ)
unnamed: C9.1, C10.1, C11.1

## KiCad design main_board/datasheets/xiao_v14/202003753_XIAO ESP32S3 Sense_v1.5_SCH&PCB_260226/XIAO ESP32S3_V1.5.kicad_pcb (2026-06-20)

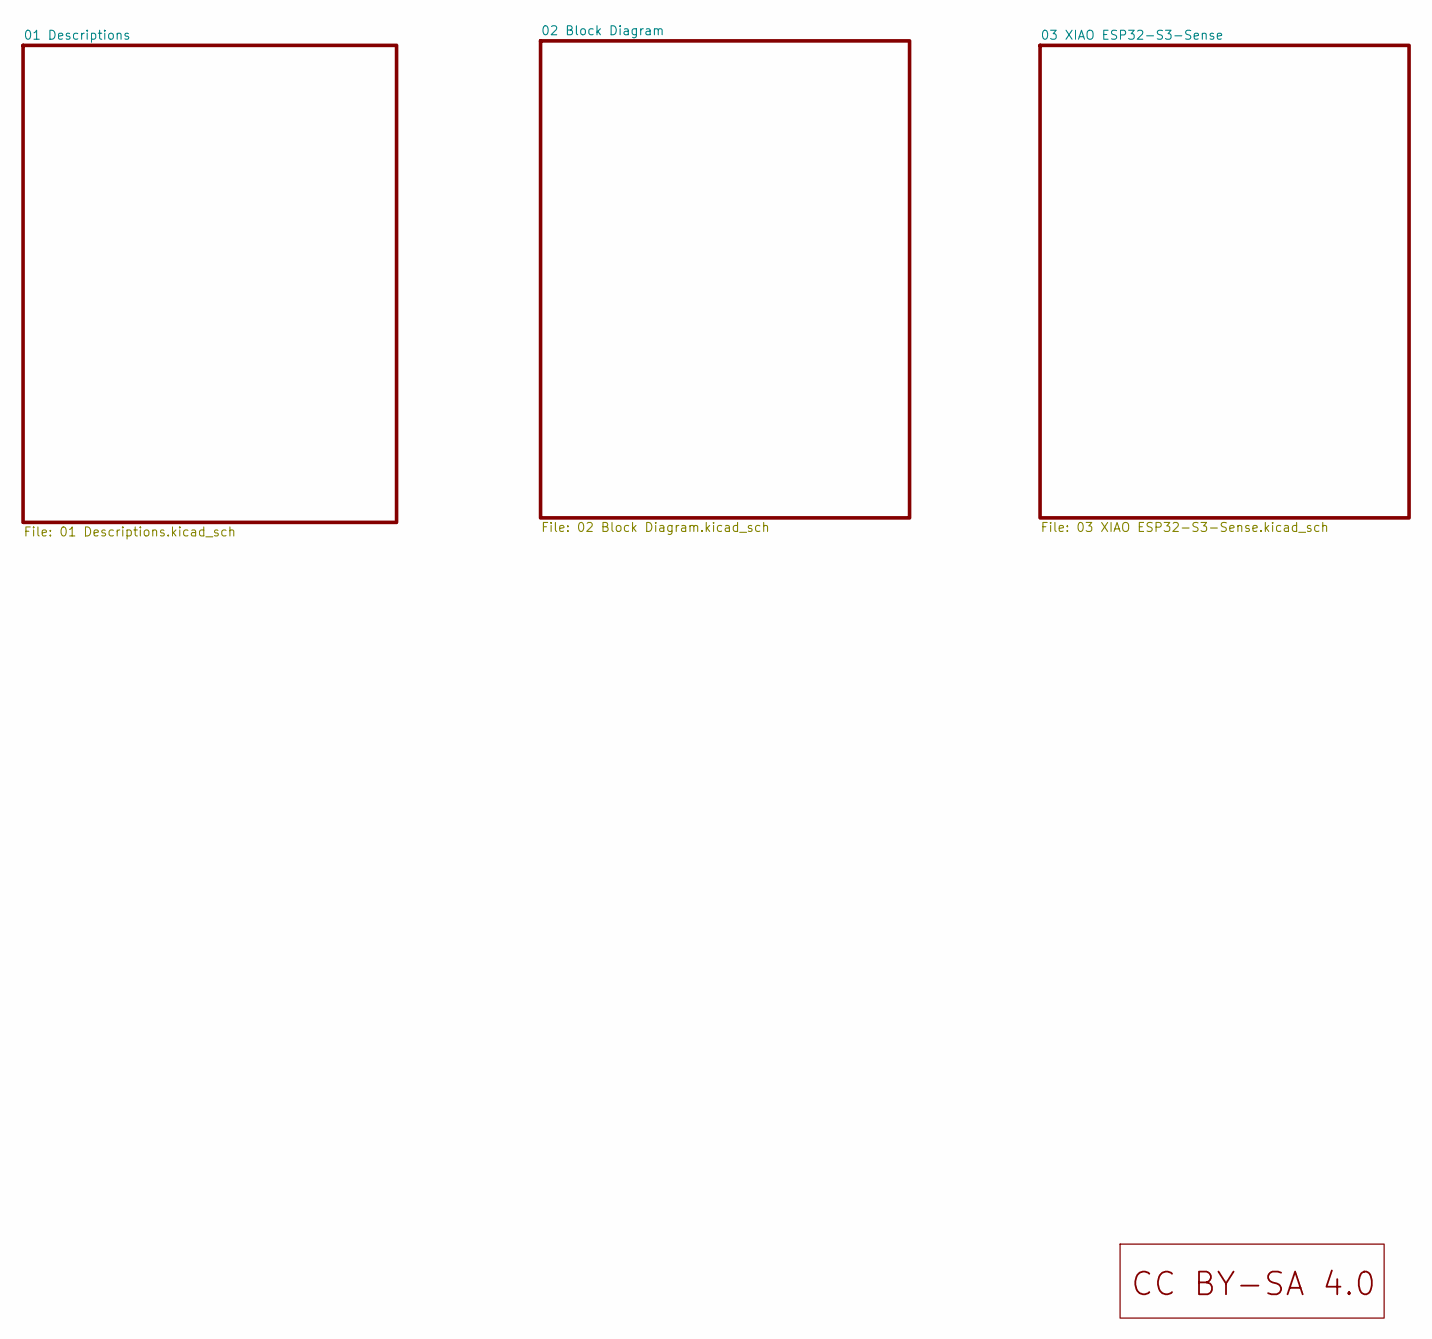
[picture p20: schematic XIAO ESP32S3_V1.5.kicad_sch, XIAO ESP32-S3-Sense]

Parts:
U6: LOGO_CC_BY-SA_4.0

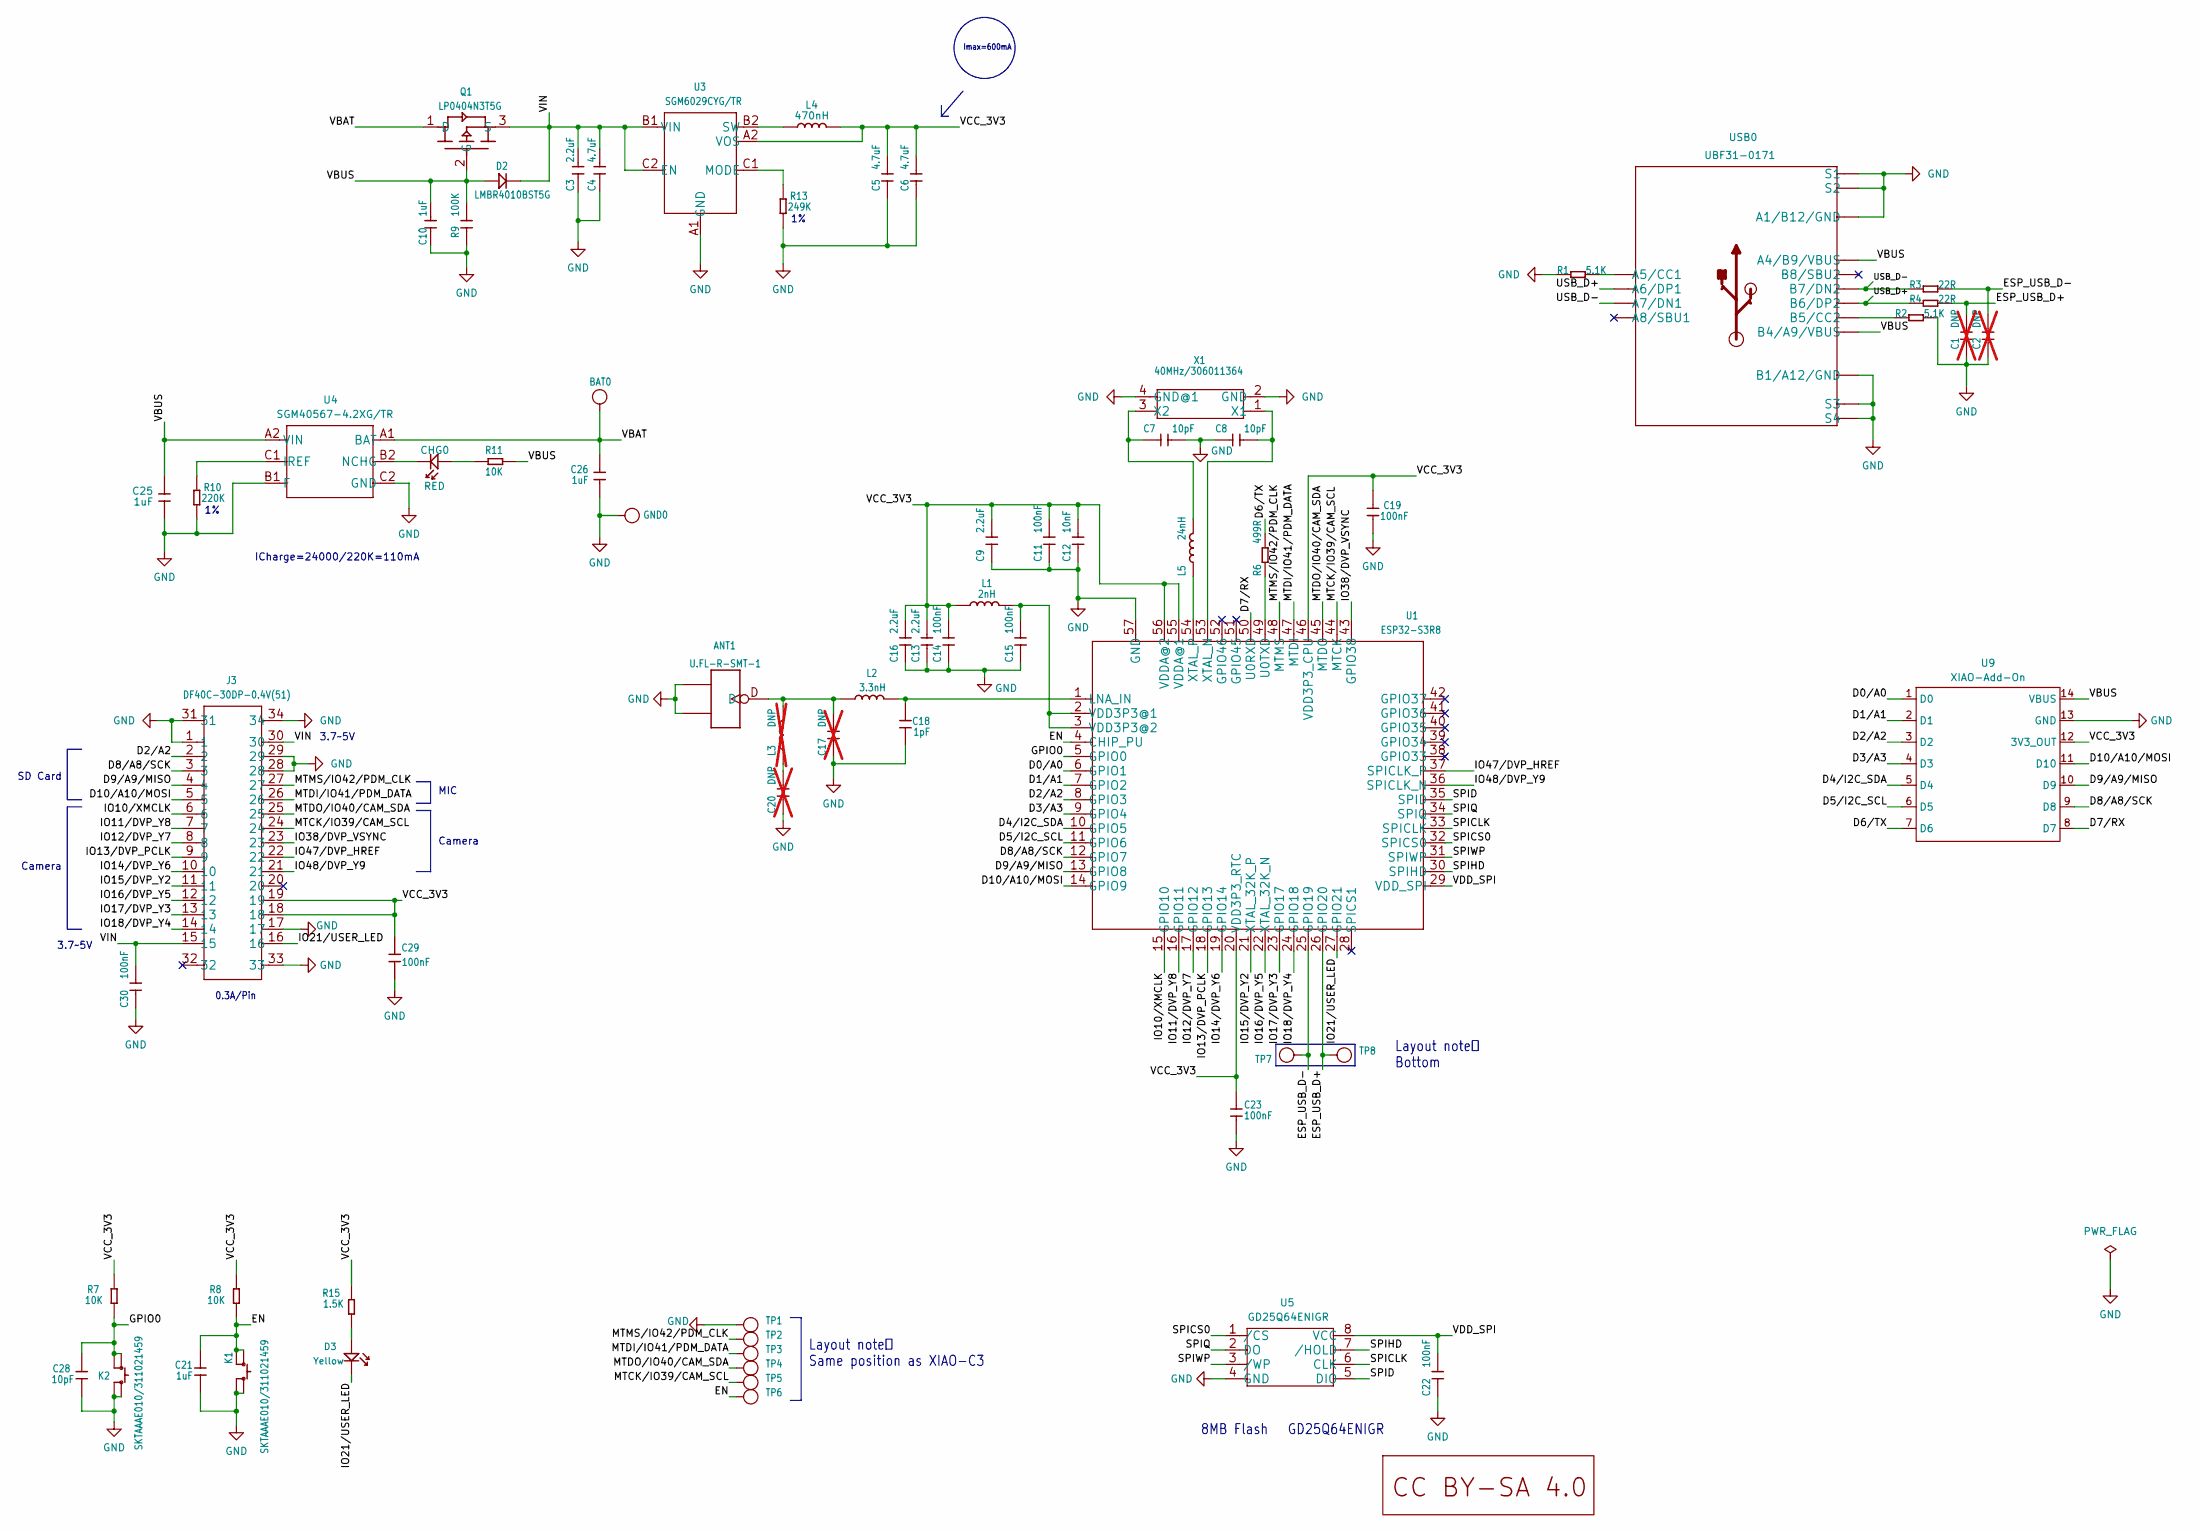
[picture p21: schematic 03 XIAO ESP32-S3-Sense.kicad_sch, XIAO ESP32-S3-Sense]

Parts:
ANT1: U.FL-R-SMT-1; U-FL3P-SMD-2.6X2.6X1.0MM
BAT0: VBAT; TP-80X40MIL
C1, C2, C17, C20: DNP; C0201; not fitted
C3, C9, C13, C16: 2.2uF; C0201
C4, C5, C6: 4.7uF; C0201
C7, C8, C28: 10pF; C0201
C10, C21, C25, C26: 1uF; C0201
C11, C14, C15, C19, C22, C23, C29, C30: 100nF; C0201
C12: 10nF; C0201
C18: 1pF; C0201
CHG0: RED; LED-0402
D2: LMBR4010BST5G; DFN1006-2L
D3: Yellow; LED-0402
GND0: GND; TP-80X40MIL
J3: DF40C-30DP-0.4V(51); BTB30-0.4-7.52X2.97X1.14
K1, K2: SKTAAAE010/311021459; SW4-SMD-2.8-2.6X1.6X0.53MM
L1: 2nH; L0201
L2: 3.3nH; L0201
L3: DNP; L0201; not fitted
L4: 470nH; L0603
L5: 24nH; L0201
Q1: LP0404N3T5G; PMOS_1.0_0.6_0.35MM
R1, R2: 5.1K; R0201
R3, R4: 22R; R0201
R6: 499R; R0201
R7, R8, R11: 10K; R0201
R9: 100K; C0201
R10: 220K; R0201
R13: 249K; R0201
R15: 1.5K; R0201
TP1, TP2, TP3, TP4, TP5, TP6, TP7, TP8: TEST-POINT'4545'; TP-D45MIL
U1: ESP32-S3R8; QFN56G-0.4-7X7MM
U3: SGM6029CYG/TR; BGA6-0.35-0.745X10.95X0.4MM
U4: SGM40567-4.2XG/TR; WLCSP-0.4-0.92X1.16X0.4MM
U5: GD25Q64ENIGR; USON8-0.8-4X3MM
U8: LOGO_CC_BY-SA_4.0
U9: XIAO-Add-On; XIAO-14P-Add-On
USB0: UBF31-0171; USB2.0-TYPE-C
X1: 40MHz/306011364; X4-SMD-1.6X1.2X0.35MM

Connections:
/03 XIAO ESP32-S3-Sense/D0/A0: U1.6 (GPIO1), U9.1 (D0)
/03 XIAO ESP32-S3-Sense/D1/A1: U1.7 (GPIO2), U9.2 (D1)
/03 XIAO ESP32-S3-Sense/D2/A2: J3.2, U1.8 (GPIO3), U9.3 (D2)
/03 XIAO ESP32-S3-Sense/D3/A3: U1.9 (GPIO4), U9.4 (D3)
/03 XIAO ESP32-S3-Sense/D4/I2C_SDA: U1.10 (GPIO5), U9.5 (D4)
/03 XIAO ESP32-S3-Sense/D5/I2C_SCL: U1.11 (GPIO6), U9.6 (D5)
/03 XIAO ESP32-S3-Sense/D6/TX: R6.2, U9.7 (D6)
/03 XIAO ESP32-S3-Sense/D7/RX: U1.50 (U0RXD), U9.8 (D7)
/03 XIAO ESP32-S3-Sense/D8/A8/SCK: J3.3, U1.12 (GPIO7), U9.9 (D8)
/03 XIAO ESP32-S3-Sense/D9/A9/MISO: J3.4, U1.13 (GPIO8), U9.10 (D9)
/03 XIAO ESP32-S3-Sense/D10/A10/MOSI: J3.5, U1.14 (GPIO9), U9.11 (D10)
/03 XIAO ESP32-S3-Sense/EN: C21.2, K1.1 (A0), K1.3 (A1), R8.1, TP6.T, U1.4 (CHIP_PU)
/03 XIAO ESP32-S3-Sense/ESP_USB_D+: C1.2, R4.2, TP8.T, U1.26 (GPIO20)
/03 XIAO ESP32-S3-Sense/ESP_USB_D-: C2.2, R3.2, TP7.T, U1.25 (GPIO19)
/03 XIAO ESP32-S3-Sense/GPIO0: C28.2, K2.1 (A0), K2.3 (A1), R7.1, U1.5 (GPIO0)
/03 XIAO ESP32-S3-Sense/IO10/XMCLK: J3.6, U1.15 (GPIO10)
/03 XIAO ESP32-S3-Sense/IO11/DVP_Y8: J3.7, U1.16 (GPIO11)
/03 XIAO ESP32-S3-Sense/IO12/DVP_Y7: J3.8, U1.17 (GPIO12)
/03 XIAO ESP32-S3-Sense/IO13/DVP_PCLK: J3.9, U1.18 (GPIO13)
/03 XIAO ESP32-S3-Sense/IO14/DVP_Y6: J3.10, U1.19 (GPIO14)
/03 XIAO ESP32-S3-Sense/IO15/DVP_Y2: J3.11, U1.21 (XTAL_32K_P)
/03 XIAO ESP32-S3-Sense/IO16/DVP_Y5: J3.12, U1.22 (XTAL_32K_N)
/03 XIAO ESP32-S3-Sense/IO17/DVP_Y3: J3.13, U1.23 (GPIO17)
/03 XIAO ESP32-S3-Sense/IO18/DVP_Y4: J3.14, U1.24 (GPIO18)
/03 XIAO ESP32-S3-Sense/IO21/USER_LED: D3.-, J3.16, U1.27 (GPIO21)
/03 XIAO ESP32-S3-Sense/IO38/DVP_VSYNC: J3.23, U1.43 (GPIO38)
/03 XIAO ESP32-S3-Sense/IO47/DVP_HREF: J3.22, U1.37 (SPICLK_P)
/03 XIAO ESP32-S3-Sense/IO48/DVP_Y9: J3.21, U1.36 (SPICLK_N)
/03 XIAO ESP32-S3-Sense/MTCK/IO39/CAM_SCL: J3.24, TP5.T, U1.44 (MTCK)
/03 XIAO ESP32-S3-Sense/MTDI/IO41/PDM_DATA: J3.26, TP3.T, U1.47 (MTDI)
/03 XIAO ESP32-S3-Sense/MTDO/IO40/CAM_SDA: J3.25, TP4.T, U1.45 (MTDO)
/03 XIAO ESP32-S3-Sense/MTMS/IO42/PDM_CLK: J3.27, TP2.T, U1.48 (MTMS)
/03 XIAO ESP32-S3-Sense/SPICLK: U1.33 (SPICLK), U5.6 (CLK)
/03 XIAO ESP32-S3-Sense/SPICS0: U1.32 (SPICS0), U5.1 (/CS)
/03 XIAO ESP32-S3-Sense/SPID: U1.35 (SPID), U5.5 (DIO)
/03 XIAO ESP32-S3-Sense/SPIHD: U1.30 (SPIHD), U5.7 (/HOLD)
/03 XIAO ESP32-S3-Sense/SPIQ: U1.34 (SPIQ), U5.2 (DO)
/03 XIAO ESP32-S3-Sense/SPIWP: U1.31 (SPIWP), U5.3 (/WP)
/03 XIAO ESP32-S3-Sense/USB_D+: R4.1, USB0.A6 (A6/DP1), USB0.B6 (B6/DP2)
/03 XIAO ESP32-S3-Sense/USB_D-: R3.1, USB0.A7 (A7/DN1), USB0.B7 (B7/DN2)
/03 XIAO ESP32-S3-Sense/VBAT: BAT0.1 (T), C26.1, Q1.1 (D), U4.A1 (BAT)
/03 XIAO ESP32-S3-Sense/VBUS: C10.1, C25.1, D2.+, Q1.2 (G), R9.2, R11.1, U4.A2 (VIN), U9.14 (VBUS), USB0.A4_B9 (A4/B9/VBUS), USB0.B4_A9 (B4/A9/VBUS)
/03 XIAO ESP32-S3-Sense/VCC_3V3: C5.2, C6.2, C9.2, C11.2, C12.2, C13.2, C14.2, C16.2, C19.2, C23.1, C29.2, J3.18, J3.19, L1.1, L4.2, R7.2, R8.2, R15.2, U1.20 (VDD3P3_RTC), U1.46 (VDD3P3_CPU), U1.55 (VDDA@1), U1.56 (VDDA@2), U3.A2 (VOS), U9.12 (3V3_OUT)
/03 XIAO ESP32-S3-Sense/VDD_SPI: C22.2, U1.29 (VDD_SPI), U5.8 (VCC)
/03 XIAO ESP32-S3-Sense/VIN: C3.1, C4.1, C30.2, D2.-, J3.15, J3.30, Q1.3 (S), U3.B1 (VIN), U3.C2 (EN)
GND: ANT1.GND1, ANT1.GND2, C1.1, C2.1, C3.2, C4.2, C5.1, C6.1, C7.2, C8.1, C9.1, C10.2, C11.1, C12.1, C13.1, C14.1, C15.1, C16.1, C17.1, C18.1, C19.1, C20.1, C21.1, C22.1, C23.2, C25.2, C26.2, C28.1, C29.1, C30.1, GND0.1 (T), J3.1, J3.17, J3.28, J3.29, J3.31, J3.33, J3.34, K1.2 (B0), K1.4 (B1), K2.2 (B0), K2.4 (B1), R1.1, R2.2, R9.1, R10.1, R13.1, TP1.T, U1.57 (GND), U3.A1 (GND), U4.B1 (F), U4.C2 (GND), U5.4 (GND), U9.13 (GND), USB0.A1_B12 (A1/B12/GND), USB0.B1_A12 (B1/A12/GND), USB0.S1, USB0.S2, USB0.S3, USB0.S4, USB0.S5 (S1), USB0.S6 (S2), X1.2 (GND), X1.4 (GND@1)
unnamed: ANT1.D, C17.2, L2.1, L3.2
unnamed: C20.2, L3.1
unnamed: CHG0.+, R11.2
unnamed: D3.+, R15.1
unnamed: C18.2, L2.2, U1.1 (LNA_IN)
unnamed: R6.1, U1.49 (U0TXD)
unnamed: C15.2, L1.2, U1.2 (VDD3P3@1), U1.3 (VDD3P3@2)
unnamed: C8.2, U1.53 (XTAL_N), X1.1 (X1)
unnamed: L5.1, U1.54 (XTAL_P)
unnamed: R13.2, U3.C1 (MODE)
unnamed: L4.1, U3.B2 (SW)
unnamed: R10.2, U4.C1 (IREF)
unnamed: CHG0.-, U4.B2 (NCHG)
unnamed: R1.2, USB0.A5 (A5/CC1)
unnamed: R2.1, USB0.B5 (B5/CC2)
unnamed: C7.1, L5.2, X1.3 (X2)

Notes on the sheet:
SD Card
Layout note： Bottom
Camera
ICharge=24000/220K=110mA
MIC
Layout note： Same position as XIAO-C3
Imax=600mA
3.7~5V
0.3A/Pin
8MB Flash GD25Q64ENIGR

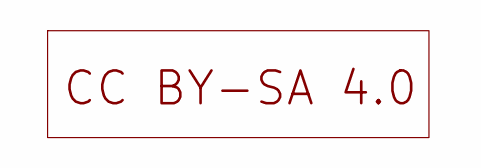
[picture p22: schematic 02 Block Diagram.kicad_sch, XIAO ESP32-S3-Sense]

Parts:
U7: LOGO_CC_BY-SA_4.0

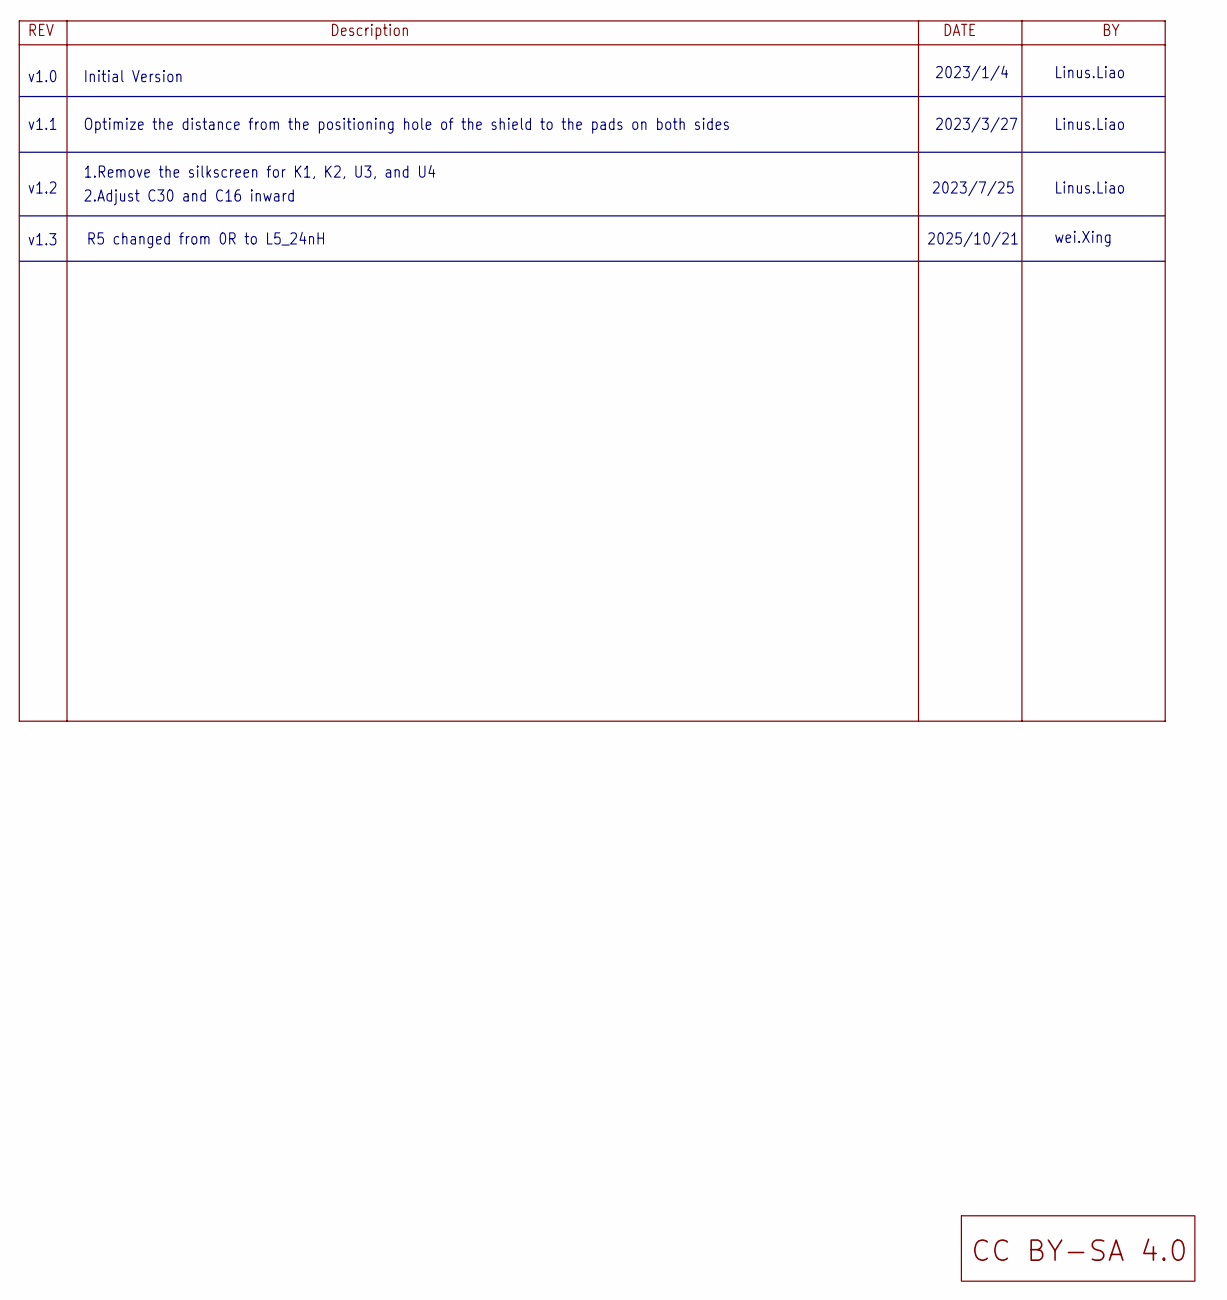
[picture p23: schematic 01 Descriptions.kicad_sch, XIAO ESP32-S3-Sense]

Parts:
U2: LOGO_CC_BY-SA_4.0

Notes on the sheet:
wei.Xing
Initial Version
R5 changed from 0R to L5_24nH
2.Adjust C30 and C16 inward
v1.1
v1.3
Linus.Liao
v1.0
2025/10/21
2023/7/25
v1.2
2023/1/4
1.Remove the silkscreen for K1, K2, U3, and U4
Optimize the distance from the positioning hole of the shield to the pads on both sides
2023/3/27

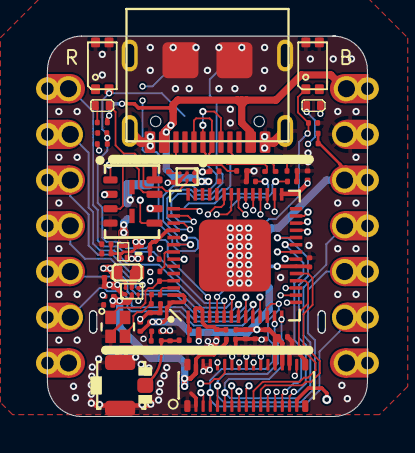
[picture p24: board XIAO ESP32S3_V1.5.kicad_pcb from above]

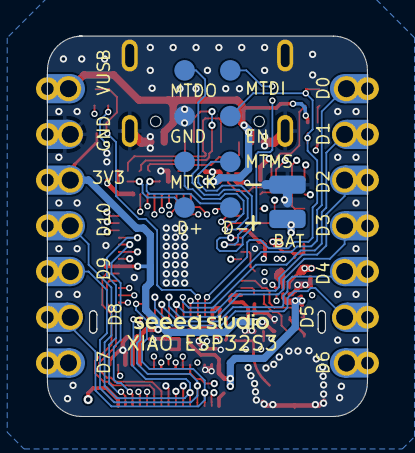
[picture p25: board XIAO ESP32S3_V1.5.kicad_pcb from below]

Board: 4 copper layers, 17.8 x 21.1 mm, 70 parts (10 on the bottom side), 62 nets.

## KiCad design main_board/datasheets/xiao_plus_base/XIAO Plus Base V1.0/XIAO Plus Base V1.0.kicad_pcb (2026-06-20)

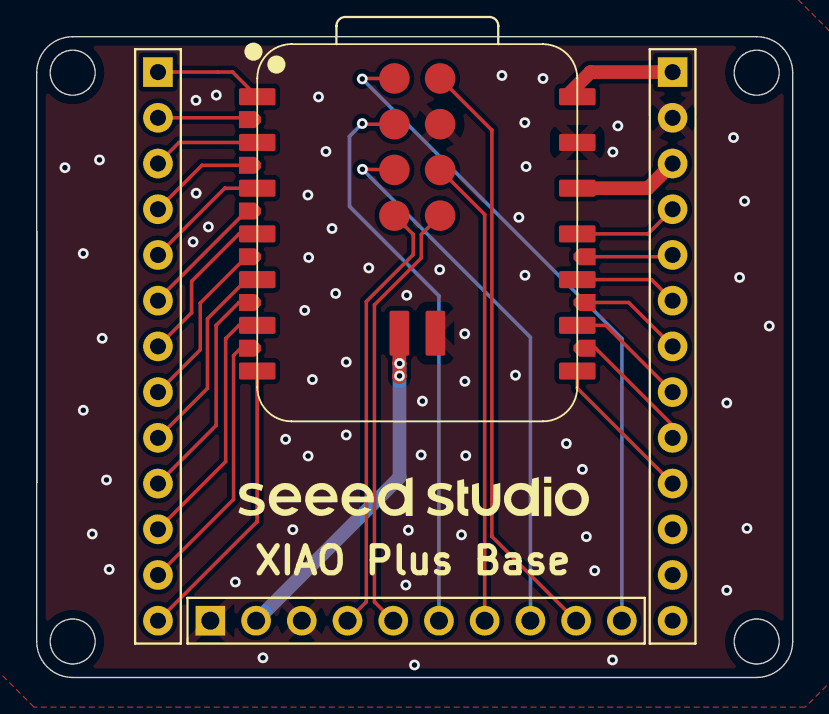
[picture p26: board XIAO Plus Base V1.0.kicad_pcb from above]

Board: 2 copper layers, 42.0 x 35.6 mm, 4 parts (0 on the bottom side), 31 nets.

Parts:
J1, J2: Header 1x13 2.54mm; H11-2.54-35
J3: Header 1x10 2.54mm; H10-2.54
U1: XIAO-ESP32-S3-Plus-SMD

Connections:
/BAT: J3.2, U1.32
/D0/A0: J1.1, U1.1
/D1/A1: J1.3, U1.2
/D2/A2: J1.5, U1.3
/D3/A3: J1.7, U1.4
/D4/A4/I2C_SDA: J1.9, U1.5
/D5/A5/I2C_SCL: J1.11, U1.6
/D6/TX: J1.13 (11), U1.7
/D7/RX: J2.10, U1.8
/D8/A8/SCK: J2.8, U1.9
/D9/A9/MISO: J2.6, U1.10
/D10/A10/MOSI: J2.4, U1.11
/D+: J3.5, U1.31
/D-: J3.4, U1.30
/EN: J3.6, U1.26
/IO10/XMCLK/ADC_BAT: J1.12 (11), U1.20
/IO11/DVP_Y8/SPI_MOSI1: J2.9, U1.21
/IO12/DVP_Y7/SPI_MISO1: J2.7, U1.22
/IO13/DVP_PCLK/SPI_SCK1: J2.5, U1.23
/IO38/DVP_VSYNC/I2S_SD: J1.2, U1.15
/MTCK: J3.7, U1.29
/MTCK/IO39/CAM_SCL/I2S_SCK: J1.4, U1.16
/MTDI: J3.10, U1.24
/MTDI/IO41/PDM_DATA/RX1: J1.8, U1.18
/MTDO: J3.9, U1.25
/MTDO/IO40/CAM_SDA/I2S_WS: J1.6, U1.17
/MTMS: J3.8, U1.28
/MTMS/IO42/PDM_CLK/TX1: J1.10, U1.19
/VBUS: J2.1, U1.14
/VCC_3V3: J2.3, U1.12
GND_POWER: J2.2, J3.1, J3.3, U1.13, U1.27, U1.33

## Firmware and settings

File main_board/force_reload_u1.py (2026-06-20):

#!/usr/bin/env python3
"""
Force-reload U1's footprint from the New_Library file.
KiCad's UI "Update Footprints from Library" thinks U1 is already current
(same nickname:name), but the in-PCB copy has only 15 pads while the
library file has 24. Forcibly swap the footprint, preserving:
- position, rotation, layer (top/bottom)
- value, reference
- net assignments for pads 1-15 (16-24 will inherit whatever the
  schematic netlist sync writes next time you Update PCB from Schematic)
"""
import os, sys
import pcbnew

BOARD = '/Users/ppisljar/Sonatino/kicad_project/esp32audio/esp32audio.kicad_pcb'
LIB_DIR = '/Users/ppisljar/Sonatino/kicad_project/New_Library.pretty'
LIB_NICK = 'New_Library'
FP_NAME = 'XIAO_ESP32-S3_SMD'
REF = 'U1'

b = pcbnew.LoadBoard(BOARD)
io = pcbnew.PCB_IO_MGR.FindPlugin(pcbnew.PCB_IO_MGR.KICAD_SEXP)

fp = b.FindFootprintByReference(REF)
if fp is None:
    print(f"ERROR: {REF} not found on board"); sys.exit(2)

pos = pcbnew.VECTOR2I(fp.GetPosition().x, fp.GetPosition().y)
rot = fp.GetOrientation()
on_bottom = (fp.GetLayer() == pcbnew.B_Cu)
value = fp.GetValue()

# Snapshot existing pad-net assignments by pad number
pad_nets = {}
for pad in fp.Pads():
    n = pad.GetNumber()
    if n:
        pad_nets[n] = pad.GetNetname()
print(f"Snapshotted {len(pad_nets)} pad nets: {sorted(pad_nets.keys(), key=lambda x: int(x) if x.isdigit() else 99)}")

# Load fresh from library file
new_fp = io.FootprintLoad(LIB_DIR, FP_NAME)
if new_fp is None:
    print(f"ERROR: FootprintLoad({LIB_DIR}, {FP_NAME}) returned None"); sys.exit(2)

new_pads = [pad.GetNumber() for pad in new_fp.Pads()]
print(f"Library footprint has {len(new_pads)} pads: {sorted(set(new_pads), key=lambda x: int(x) if x.isdigit() else 99)}")

b.Remove(fp)
new_fp.SetReference(REF)
new_fp.SetValue(value)
new_fp.SetFPID(pcbnew.LIB_ID(LIB_NICK, FP_NAME))
b.Add(new_fp)
new_fp.SetPosition(pos)
if on_bottom:
    try:
        new_fp.SetLayerAndFlip(pcbnew.B_Cu)
    except AttributeError:
        new_fp.Flip(pos, False)
new_fp.SetOrientation(rot)

# Restore net assignments for pads that existed before
restored = 0
for pad in new_fp.Pads():
    n = pad.GetNumber()
    if n in pad_nets and pad_nets[n]:
        net_obj = b.FindNet(pad_nets[n])
        if net_obj:
            pad.SetNet(net_obj)
            restored += 1
print(f"Restored {restored} pad-net assignments")

pcbnew.SaveBoard(BOARD, b)
print(f"Saved. New pad count on {REF}: {len(new_pads)}")

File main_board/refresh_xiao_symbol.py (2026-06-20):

#!/usr/bin/env python3
"""
Replace the schematic's embedded copy of XIAO_ESP32-S3 lib_symbol with the
latest version from New_Library.kicad_sym (now has pins 1-24).
"""
import re

SCH = '/Users/ppisljar/Sonatino/kicad_project/esp32audio/esp32audio.kicad_sch'
LIB = '/Users/ppisljar/Sonatino/kicad_project/New_Library.kicad_sym'

def extract_symbol_block(text, sym_name):
    """Return (start_idx, end_idx, block_text) of (symbol "sym_name" ...)."""
    pat = re.compile(rf'\(symbol\s+"{re.escape(sym_name)}"')
    m = pat.search(text)
    if not m:
        return None
    start = m.start()
    depth = 0
    for i in range(start, len(text)):
        if text[i] == '(': depth += 1
        elif text[i] == ')':
            depth -= 1
            if depth == 0:
                return (start, i+1, text[start:i+1])
    return None

# Read library, extract the XIAO symbol block
lib = open(LIB).read()
res = extract_symbol_block(lib, 'XIAO_ESP32-S3')
assert res, "Could not find XIAO_ESP32-S3 in library"
_, _, lib_xiao = res
print(f'Library XIAO symbol: {len(lib_xiao)} bytes')

# Read schematic — find the embedded XIAO symbol within lib_symbols
sch = open(SCH).read()
# Schematic embeds symbols with prefix like "New_Library:XIAO_ESP32-S3"
res = extract_symbol_block(sch, 'New_Library:XIAO_ESP32-S3')
assert res, "Could not find New_Library:XIAO_ESP32-S3 in schematic"
sstart, send, sch_xiao = res
print(f'Schematic embedded XIAO symbol: {len(sch_xiao)} bytes')

# Build a new block: copy lib_xiao but rename to "New_Library:XIAO_ESP32-S3"
new_block = lib_xiao.replace('"XIAO_ESP32-S3"', '"New_Library:XIAO_ESP32-S3"', 1)
# Indent each line by adding tab so it matches the schematic's lib_symbols indent
# Find indent from original block
orig_indent = ''
for ch in sch[sstart-10:sstart]:
    if ch == '\t': orig_indent += '\t'
# Apply same indent to new block (very rough; KiCad re-formats on save anyway)
new_block_indented = new_block

new_sch = sch[:sstart] + new_block_indented + sch[send:]
open(SCH, 'w').write(new_sch)
print(f'Wrote schematic ({len(new_sch)} bytes). Pin count in new embedded symbol:')
new_pins = re.findall(r'\(number\s+"(\d+)"', new_block)
print(f'  pins: {sorted(set(int(n) for n in new_pins))}')

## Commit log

2026-06-20 Initial commit: ESP32 audio player main board
    KiCad project for the freeesp32 audio player main board (XIAO ESP32-S3
    based), including schematic, PCB layout, design rules, 3D models,
    component datasheets, analysis manifests, and helper scripts for net
    sync / pad cleanup / freerouting.
    [01 Descriptions.kicad_sch, 02 Block Diagram.kicad_sch, 03 XIAO ESP32-S3-Sense.kicad_sch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]
2026-06-20 Add README
    Project intro, board feature summary (XIAO ESP32-S3 + CS4344 DAC +
    APA2068 amp + microSD + LED headers), repo layout, and links to the
    companion firmware (freeesp32_ave) and session generator
    (freeesp32_ave_generator).
2026-06-20 README: add board renders and ordering instructions
    - Embed top + bottom 3D renders from KiCad (in main_board/images/)
    - Add manufacturing section covering PCBWay (recommended for assembly
    with non-LCSC parts) and JLCPCB (cheaper for bare boards / LCSC
    parts), with file pointers to outputs/Archive.zip, the BOM, and the
    pick-and-place CSVs
    - Note how to regenerate the manufacturing outputs from KiCad after
    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
2026-06-20 README: add Power section
    Document the three input options (USB-C / external 5 V / Li-ion battery),
    the TPS61023 boost path that lifts BAT+ to 5 V so the speaker amp works
    on battery, and a small "safe to combine?" table. Calls out that USB and
    external 5 V on J4 are mutually exclusive (no diode-OR) but USB+battery
    and J4+battery are both fine because D1 isolates the boost output from
    USB VBUS.
